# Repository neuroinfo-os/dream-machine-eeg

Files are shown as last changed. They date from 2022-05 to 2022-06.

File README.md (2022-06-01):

# Dream Machine
The Dream Machine, formerly known as *Traumschreiber*, is a lightweight, low-cost, mobile EEG device developed at the Neuroinforamtics group at Osnabrück University. This repository contains all affiliated projects and theses.

### This includes:
- BoardDesign: The Printed Circuit Board (PCB) design of the latest version and a collection of operation manuals of the most important hardware components
- Two App submodules, including the [standard version](https://github.com/denizmgun/EEG-DroidDesign) and an alternative version adapted for an [exemplary motor imagery task](https://github.com/denizmgun/DreamMachineThesisMod)
- The embedded system and Bluetooth Low Energy (BLE) implementation
- An implementation to perform an "Eyes Open, Eyes Closed" experiment with Labrecorder and lab streaming layer (LSL) as [submodule](https://github.com/mvidaldp/pylsl-keyboard-trigger)
- A collection of theses written with (older) versions of the Dream Machine   

*Please do not hesitate to contact us with any questions or ideas (Paria Samimi: psamimi@uni-osnabrueck.de, Laura Krieger: laura.krieger@uni-osnabrueck.de).*

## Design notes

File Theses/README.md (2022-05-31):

# Traumschreiber
The Traumschreiber system is the subject of several theses covering different research areas within Cognitive Science and Neuroinformatics. Here, the theses are collected. The following gives a brief summary of the individual projects.

#### _The Traumschreiber System - Enabling Crowd-based, Automated, Complex, Polysomnographic Sleep and Dream Experiments_ - K. Appel, Dissertation

In this dissertation the development of the Traumschreiber System as well as its evaluation is presented. The high-tech sleep mask was developed to enable naive crowd
subjects to perform complex polysomnographic sleep and dream experiments at home. It is shown that on the one hand the quality of polysomnographic data recording – including measurements of EEG, EOG, EMG and ECG–, can compete with commercial medical sleep laboratory systems. On the other hand, it was shown with two field studies that even novice subjects can conduct sleep experiment at their homes with the Traumschreiber.

## App Development

#### _Design and implementation of an Android app to  record, store and manage EEG signals_ - R. A. Rojas Campos, Master's Thesis (August 2019)

This thesis describes the most advanced Traumschreiber app to date. With the Android app, the user can collect, plot, save, manage, and share EEG sessions, recorded with the Traumschreiber system. It furthermore introduces a chatbot expert, used to inform the user about epilepsy and presents general information about epilepsy in a clear and accessible way. The code is available [in this repository](https://github.com/adrocampos/EEG-Droid).

#### _Developing and designing a mediator smartphone application for portable sleep EEG recording and biofeedback with focus on the end user experience_ - M. Jäkel, Bachelor's Thesis (February 2017)

This thesis reports on the implementation of a prototype Android application that introduces users to the sleep mask. With the app, users can, among other, connect the Traumschreiber via Bluetooth to their phones, enabling them to visualize recorded EEG data.

## Detection of Event Related Potentials with the Traumschreiber

#### _Studying Neural Correlates of Mind Wandering with Mobile EEG_ - M. Bammel, Bachelor's Thesis (April 2020)

This thesis constitutes a replication of a study by Braboszez and Delorme (2011) who identified neural markers of low alertness during mind wandering with the Traumschreiber. The experiments expose a significantly decreased alpha and beta frequency band power during mind wandering. However, the replication demonstrates that studying higher cognitive functions in a mobile setup using the Traumschreiber does not yield equivalent results compared to a stationary research graded EEG system. The full sourcecode of the project is available [in the author's repository](https://github.com/mbammel/BscThesis).

#### _Auditory Evoked Potentials with Mobile EEG_ - M. Vidal De Palol, Master's Thesis (March 2019)

This project combines the development of an Android App for real-time EEG visualization and recording and an experiment to assess the capability of the device for recording Auditory Evoked Potentials.

#### _Measuring vMMN, P300 and AEPs with a mobile EEG system_ - M. Reimann, Bachelor's Thesis (September 2018)

Within this thesis the potential of the Traumschreiber as mobile EEG system is explored by evaluating its usability and ability to detect event-related potentials (ERP). It is shown that the device is able to produce good and very good results for the ERP under consideration.

#### _Analyzing event-related potentials in 8-channel EEG data using machine learning methods_ - A.-K. Schalkamp, Bachelor's Thesis (September 2018)

This thesis describes a study performed to evaluate whether EEG data acquired with the Traumschreiber can be used with traditional and single-trial analysis. Furthermore, it expands on the importance of electrode placement.

## Eye Position and Gaze Estimation

#### _Eye gaze estimation and gesture recognition using mobile EEG, An application for sleep communication_ - V. Amo Olea, Master's Thesis (September 2019)

Within this project a real-time eye-gaze estimation and gesture recognition
system using Electrooculography (EOG) was developed. A Convolutional Neural Net was trained to recognize eye-typing gestures and three command gestures from movement with closed eyes.

#### _Extracting Eye Positions from Electrooculographic Recordings Using a Machine Learning Approach_ - F. Laubisch, Bachelor's Thesis (September 2016)

In this thesis the relationship between EOG data provided by the Traumschreiber and eye position obtained with a wearable eye tracking device is assessed. It is shown that the sole EOG data is not yet sufficient to produce reliable eye tracking information.

## Sleep and Lucid Dreaming Research

#### _Conducting a Polysomnographic, Automated Auditory Stimulation Sleep Experiment Using a Portable High-Tech Sleep Mask_ - L.S. Mandt, Bachelor's Thesis (April 2017)
The field study discussed in this thesis evaluates the portable high-tech sleep mask for home-based sleep experiments using polysomnography. Additionally, it examines whether the arousal threshold of individual participants can be determined by exposing them to auditory stimulation during the night.

#### _The Scienticity of Lucid Dream Research - A Theoretical and Empirical Approach_ - K. Lüth, Bachelor's Thesis (July 2015)

This work discusses the science-theoretical and historical background of lucid dream research. It presents a survey concerned with the attitude the public has towards the field. The survey showed that the public has a positive opinion.

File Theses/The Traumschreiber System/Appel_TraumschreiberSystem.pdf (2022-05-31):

# The Traumschreiber System

Enabling Crowd-based, Automated,

## Complex, Polysomnographic Sleep and Dream Experiments

Dissertation

Kristoffer Appel

## Abstract

Sleep and dreaming are important research topics. Unfortunately, the methods for researching them have several shortcomings. In-laboratory polysomnographic sleep and dream research is a costly, time-consuming and effortful endeavor, often resulting in small subject counts. Moreover, the unfamiliar sleeping environment can lead to distorted measurements as compared to the natural sleep environment at the subject’s home.

Conducting sleep and dream experiments in the field by a crowd of subjects could be a solution. However, complex experiment paradigms cannot be investigated this way, because there are no tools available, which enable naive subjects to carry out complex polysomnographic studies on their own.

The Traumschreiber system, which is developed and evaluated in this dissertation, offers a solution to this problem. It consists of a high-tech sleep mask and a minicomputer, and enables naive crowd subjects to perform complex polysomnographic sleep and dream experiments at home. On the one hand, it instructs the crowd subject, what to do when. On the other hand, it controls the experiment during the time the subject is asleep, analyzing the data in real-time using state-of-the art machine learning techniques. The rationale behind is to enable a big data approach to sleep and dream research, using the data recorded by a crowd of subjects for large-scale investigations about sleep and dreaming, with low costs for the researcher.

After describing the development process of the Traumschreiber system, its usefulness regarding crowd-based automated polysomnographic field studies is evaluated. First, it is validated against a commercial medical polysomnographic sleep laboratory system, demonstrating its good polysomnographic data recording capabilities – including measurements of EEG, EOG, EMG and ECG –, which enable the researcher to identify typical sleep patterns like slow waves or rapid eye movements as well as sleep stages in the recorded data.

Furthermore, two field studies show, that the Traumschreiber system can be used successfully by naive subjects to conduct complex sleep experiments at their homes. This includes acoustic stimulation of the sleeping subject as well as sleep stage dependent activities of the system. The sleep staging algorithm implements a Keras/Tensorflow based neural network approach, which demonstrates the system’s readiness for state-of-the-art machine learning techniques. However, the currently used neural network is kept very simple and can determine the sleep stage not very reliably; it should be further developed and trained on more data of more subjects.

The Traumschreiber system will be made available under an open source license, enabling any researcher to use, modify or further develop it. A description, how to produce arbitrarily many entities of the Traumschreiber system, is given in this dissertation and shows that one system can be produced at low costs in a short amount of time (production costs per piece around 140 EUR plus 80 EUR for the other parts of the system, production time: one hour per item).

Taken together, a new tool for sleep and dream research is now available, which enables a crowd-based approach of gathering polysomnographic data from complex sleep and dream experiments with only low resource needs for the scientist.

## Table of Contents

2.3.3.2 Description of the preparation steps for a Traumschreiber system study....57

3.1.2.2.3 Real-time data processing using encapsulated, modular scripts.......77

3.2.3 Third study: Preparing polysomnographic crowd experiments | 96
3.2.3.1 Description of production work step and cost analysis | 96
3.2.3.2 Programming the experiment | 107
3.2.4 Fourth study: A crowd-based polysomnographic experiment | 108
3.2.4.1 General results | 108
3.2.4.2 Data quality | 109
3.2.4.3 Sleep quality | 115
3.2.4.4 Ease of use, comfort and durability of the Traumschreiber system | 115
3.2.4.5 Feedback of the subjects to the sleep mask and the experiment | 116
3.2.4.6 Automatic sleep scoring algorithm and subject-specific adjustment | 116
3.2.4.7 N3 and REM sleep differences | 118
3.2.4.8 Sleep depth | 119
3.2.4.9 Workload of the experimenter and costs of the experiment | 120
4 Discussion | 121
4.1 General discussion | 121
4.2 Discussion of the development process and evaluation studies | 123
4.2.1 Discussion of the development process | 123
4.2.2 Evaluation studies | 124
4.2.2.1 First study: Sleep laboratory validation | 126
4.2.2.2 Second study: Home-based prototype study | 127
4.2.2.3 Third study: Preparing polysomnographic crowd experiments | 128
4.2.2.4 Fourth study: A crowd-based polysomnographic experiment | 129
4.3 Future research directions and prospects | 132
4.3.1 Future research directions | 132
4.3.1.1 Further developing the Traumschreiber system | 132
4.3.1.2 Suggestions for further studies with the Traumschreiber system | 135
4.3.2 Future prospects | 137
5 References | 139
Appendices | 150

## Figures

Figure 3.13: Night overview plot | 82
Figure 3.14: Detailed view plot | 82
Figure 3.15: The events dropdown menu | 83
Figure 3.16: Specifying a filter in the config xml file | 84
Figure 3.17: Manual sleep scoring with the Traumschreiber system | 85
Figure 3.18: Real-time sleep stage predictions of the Traumschreiber system | 86
Figure 3.19: The same predictions, averaged using a 20 minute sliding window | 87
Figure 3.20: Polysomnographic data recorded with the ALICE system | 88
Figure 3.21: The same data recorded with the Traumschreiber system | 89
Figure 3.22: Sleep staging comparison between the two systems | 91
Figure 3.23: Sleep quality in the first night and the control night | 92
Figure 3.24: Feeling of recovery after the experimental night and the control night | 93
Figure 3.25: Comparison of acoustic stimuli regarding arousals | 95
Figure 3.26: Back and front side of the equipped PCB | 97
Figure 3.27: All parts of 20 complete Traumschreiber systems | 100
Figure 3.28: The battery holder before cutting | 101
Figure 3.29: The battery holder after cutting | 101
Figure 3.30: Screenshot of the video tutorial (1) | 103
Figure 3.31: Sewing pattern for the sleep mask bag | 104
Figure 3.32: Screenshot of the video tutorial (2) | 105
Figure 3.33: Example of the bio signal calibration procedure | 109
Figure 3.34: Example of a nightly arousal procedure (1) | 110
Figure 3.35: Example of a nightly arousal procedure (2) | 110
Figure 3.36: Example of REM sleep recorded by the Traumschreiber system | 112
Figure 3.37: Unfiltered, raw data example of a recording with bad quality | 112
Figure 3.38: Example of a recording with good data quality | 113
Figure 3.39: Example of a recording with bad data quality | 113
Figure 3.40: Recording success during the second and third night | 114
Figure 3.41: Automatic sleep staging comparison | 117
Figure 3.42: Difference between REM and N3 sleep dreams (1) | 118
Figure 3.43: Difference between REM and N3 sleep dreams (2) | 118
Figure 3.44: Difference between REM and N3 sleep dreams (3) | 119
Figure 3.45: Difference between REM and N3 sleep dreams (4) | 119
Figure 3.46: Difference between REM and N3 sleep | 119

## Tables

Table 1.1: Comparison of consumer sleep recording devices | 31
Table 2.1: Overview of the main electric development iterations | 46
Table 3.1: Overview of the electrode positions and recorded channels | 70
Table 3.2: Detailed description of the experiment xml file commands | 74
Table 3.3: Polysomnographic graphoelements in both systems | 89
Table 3.4: Reasons were for having trouble falling asleep | 94
Table 3.5: Overview of the work steps for producing a Traumschreiber system | 96
Table 3.6: Recordings with a good EEG, EMG, EOG, and ECG signal | 114

## Abbreviations

AI | Artificial Intelligence
ADC | Analog-to-Digital Converter
BLE | Bluetooth Low Energy
CSV | Comma-Separated Values
ECG | Electrocardiography
ECTS | European Credit Transfer System
EEG | Electroencephalography
EMG | Electromyography
EOG | Electrooculography
EUR | Euro
FoR | Feeling of Recovery
FFT | Fast Fourier Transform
GUI | Graphical User Interface
HEOG | Horizontal Electrooculography
IC | Integrated Circuit
ICSD-3 | International Classification of Sleep Disorders – Third Edition
InAmp | Instrumentation Amplifier
JSON | JavaScript Object Notation
LED | Light-Emitting Diode
N1 | Sleep Stage N1
N2 | Sleep Stage N2
N3 | Sleep Stage N3
NDR | Norddeutscher Rundfunk
OpAmp | Operational Amplifier
PCB | Printed Circuit Board
Ph.D. | Doctor of Philosophy
POSIX | Portable Operating System Interface
RAM | Random-access Memory
REM | Rapid Eye Movement Sleep
SF-A | Schlaffragebogen A (Sleep Questionnaire A)
SQ | Sleep Quality
SWS | Slow Wave Sleep
UART | Universal Asynchronous Receiver Transmitter
UDP | User Datagram Protocol
USB | Universal Serial Bus
USD | US Dollar
VEOG | Vertical Electrooculography
XML | Extensible Markup Language

## Acknowledgements

I would like to thank quite a number of people, who supported me during my Ph.D. time. First of all, my supervisor, Prof. Dr. Pipa, from whom I learned a lot about doing science in general and about neuroinformatics, about advanced EEG analysis, about the “hidden” tasks a researcher has to do like networking and about budgeting. Moreover, I’d like to thank him for financing my Ph.D. position and parts of my experiments, even though sleep and dream science is not his main research interest, and for all the freedom throughout my Ph.D. and “letting me do my thing”.
Then, the other members of the PhD board, for their willingness to read and evaluate this dissertation: Prof. Dr. Kühnberger, Prof. Dr. Schredl and Prof. Dr. Dresler.
Next, I would like to thank all my co-workers in and around the office and the sleep laboratory, for valuable discussions and the good working atmosphere, and especially Mr. Leugering, who played a major role in developing the electro-technical parts of the hightech sleep mask discussed in this dissertation and parts of the software to steer it.
Then, all the students, who worked together with me in one of the several projects, on which this dissertation is built. First, the 10 bachelor students writing their thesis in the field of sleep and dreaming, with me as their supervisor. Second, all the students from the Student Initiative Sleep & Dream, who not only conducted a complete sleep laboratory study with 20 subjects in their leisure time, but also helped building up a very active sleep & dream student community in Osnabrueck, with excursions to far away countries, movie nights, lucid dreaming workshops and more. Third, the master students of the study project on Sleep and Memory, which I supervised, for all the efforts they put into conducting the first sleep laboratory study of this kind in Osnabrueck. Fourth, the students of my seminars “Sleep & Dream”, “Reading Club: Dreams and Dreaming”, and “Textile Design of a Hightech Sleep Mask I + II”, who also contributed to the success of this dissertation with inspiration and ideas, and Prof. Dr. Hähnel for the joint supervision of the textile design courses.
Next, I would like to thank the scientists from my personal research network, for sharing their knowledge with me, the inspiring discussions, and the great time at conferences, workshops and other meetings.

I would also like to thank Prof. Dr. Steiger and his group at the Max Planck Institute of Psychiatry in Munich for the opportunity to learn, how sleep research is conducted in a professional sleep laboratory, during my stay there as a visiting researcher.
Moreover, I would like to thank Prof. Dr. Young from the Muenster University Hospital, for his support, the opportunity to collaborate in a joint study, and especially the mediation of the donation of a professional sleep laboratory equipment to the Osnabrueck Student Initiative Sleep & Dream. Also I would like to thank Prof. Dr. König for letting me and the other students use his sleep research equipment.
Furthermore, I would like to thank the members of the Osnabrueck University ethics committee for their helpful advice and consulting during in total four ethics proposals. Next, I would like to thank Mrs. Jungeilges and Mrs. Eibisch for their help with all the administrative things, which need to be done in German bureaucracy.
Also, I would like to thank the Hans-Mühlenhoff-Stiftung zur Förderung leistungsfreudiger Jugend and the German Sleep Society for their financial support of my experiments, in total worth nearly 10.000 EUR, without which some studies of this dissertation could not have been conducted.
And, last, but not least, I would like to thank all my friends and family for the continuous support throughout the last years.
Thank you!

## Preface – Reflecting on my scientific activities

The highest academic degree, the Ph.D., is awarded for scientific achievements and proves that the holder of the degree is able to conduct elaborated scientific works on his or her own¹
. Before starting with the actual dissertation, I would like to briefly reflect on my scientific activities during the past four years.

It all started by following a personal interest of mine – lucid dreaming. I started researching it in my leisure time using a low-budget one-channel sleep EEG device. One year later, I created a student initiative about sleep and dreaming at my university in 2012. I motivated fellow students to conduct our own research in the field of sleep and dreaming using portable high-tech sleep devices, applied for funding from the general students’ committee, and organized regular meetings. Subsequently, I wrote my master’s thesis about how it is possible to communicate with (sleeping!) lucid dreamers in real-time. Fortunately, Prof. Dr. Pipa offered me the possibility to extend my research during a Ph.D.. I organized two university rooms and raised a large equipment donation of a medical device manufacturer, enabling me to conduct research in my own fully-equipped sleep laboratory. I went to the Max Planck Institute of Psychiatry in Munich as a visiting researcher, where I took part in a research project on lucid dreaming using a high-density 128 channel EEG, and learned, how to conduct professional sleep and dream research. This knowledge I then transferred to my sleep laboratory in Osnabrueck, and passed it on to fellow students of the student initiative, as well as during seminars I taught. Besides conducting research, life in academia also includes teaching. I offered courses worth 40 ECTS points in total; sometimes more than 100 students participated in my seminars. I supervised 19 bachelor’s and master’s theses and a one-year study project of ten master students.
The before mentioned student initiative grew steadily and became the largest young scientists sleep and dream research group in Germany, if not worldwide. We conducted workshops and experiments in the sleep laboratory and went on three scientific excursions, e. g. one week in spring 2016 to sleep researchers in Finland. More details

1 Osnabrueck University Ph.D. regulations “Promotionsordnung des Fachbereichs Humanwissenschaften der Universität Osnabrueck für die Verleihung des Grades Ph.D. in Cognitive Science” (2011), § 1.

about the student initiative can be found in the article “Kurzvorstellung der Studentischen Initiative Sleep & Dream Osnabrueck”, published in the journal “Somnologie” (Appel, 2017, see appendix).
There were several research projects of mine, which I conducted during the last years. I validated the sleep communication from my master’s thesis using polysomnographic recordings in my sleep laboratory at Osnabrueck university with experiment subjects from all over Germany. I recorded and analyzed lucid dreams with a high-density EEG at the Max Planck Institute Institute of Psychiatry in Munich. I conducted an online study about the success rate of a lucid dream induction technique, for which I used a self-developed website as a platform. I analyzed a dietary supplement regarding its effect on sleep and dreaming. I carried out a sleep laboratory study investigating the role, which sleep plays for memory processes. I conducted another questionnaire study about the public perception of lucid dreams. I successfully replicated the results of a recent study about a new lucid dreaming induction technique in my sleep laboratory, and started a study investigating the effects of lucid dreaming smartphone apps. I wrote a review paper about lucid dreaming, and an article about the same topic for the “DGSM Kompendium Schlafmedizin” of the German Sleep Society, which is used for educating purposes of sleep laboratory staff and medical doctors. I summarized a German dissertation about event-related potentials during lucid dreams and published it in a scientific journal in order to make it available to the English speaking scientific community. In many of these projects, I instructed and supervised undergraduate students, who carried out the experiments together with me as a part of their theses. Other smaller projects are not mentioned here.
I made most of this research available to the scientific community, e. g. at scientific conferences. Some of the research is already published in scientific journals as well, with the other not yet published works to follow after finishing my Ph.D.. A list of publications and conference presentations is attached at the end of this preface. Besides publishing my research in the scientific literature, it was important to me to transfer the new knowledge to the non-scientific public as well. I presented my research twice on television (NDR), in an international pop-sci magazine (The New Scientist), was interviewed by a large German internet magazine (Netzpiloten), and by journalists from Finland to Brazil (see appendix for examples).

Finally, I carried out other scientific tasks throughout my Ph.D.. From obtaining funds for my experiments (in total nearly 10.000 EUR), to writing and defending four complete ethics proposals, to acting as a reviewer in peer-reviewed journals four times. I connected the new Osnabrueck sleep and dream research to well-known researchers from various institutes, such as the Donders Institute (Nijmegen, The Netherlands), the Central Institute of Mental Health (Mannheim), the Max Planck Institute of Psychiatry (Munich), the Charité Sleep Competence Center (Berlin), the Muenster University Hospital, and Bern University (Switzerland), and cooperated with them in common research projects.
One project was not yet named in this reflection of my scientific activities: the Traumschreiber project. It is the main project of my Ph.D., and is described in larger detail in this dissertation.

List of scientific publications and conference presentations Appel, K., Pipa, G., & Dresler, M. (2017). Investigating consciousness in the sleep laboratory - an interdisciplinary perspective on lucid dreaming. Interdisciplinary Science Reviews, 1-16.

Appel, K., Pipa, G. (2017). Auditory evoked potentials in lucid dreams: a dissertation summary. International Journal of Dream Research, 10(1), 98-100.

Appel, K. (2017). Kurzvorstellung der Studentischen Initiative Sleep & Dream Osnabrueck. Somnologie, 21(3), 252-254.

Kern, S., Appel, K., Schredl, M., & Pipa, G. (2017). No effect of alpha-GPC on lucid dream induction or dream content. Somnologie, 21(3), 180-186.

Appel, K., Leugering, J., Pipa, G. (2016). Kommunikation mit Klarträumern in Echtzeit – aktuelle Möglichkeiten. Oral presentation at the 24rd Annual Conference of the German Sleep Society, Dresden, Germany.

Leugering, J., Appel, K. (2016). Traumschreiber: Eine Open Source Schlafmaske, die
Hirnaktivitäten | messen | und | beeinflussen | kann. | Oral | presentation | at | the
MetaRheinMainChaosDays of the Chaos Computer Club, Darmstadt, Germany.

Appel, K., Leugering, J., Pipa, G. (2016). “Traumschreiber”: Measuring and manipulating human sleep with a portable high-quality but low-cost polysomnographic system. Poster presentation at the 23rd Congress of the European Sleep Research Society, Bologna, Italy.

Appel, K. (2016). The Student Initiative Sleep & Dream Osnabrueck. Oral presentation at the 33rd Annual International Dream Conference, Kerkrade, Netherlands.

Appel, K., Kern, S. (2015). Phänomenologie luzider Träume und Induktionstechniken. Schulz, Geisler, Rodenbeck (Hrsg.) DGSM Kompendium Schlafmedizin. Ecomed Verlag, Landsberg, XVIII-3.9.1

Appel, K. (2015). The Student Initiative Sleep & Dream Osnabrueck. Oral presentation at the 23rd Annual Conference of the German Sleep Society, Mainz, Germany.

Appel, K., Pipa, G. (2015). Sleep Communication. Poster presentation at the Worldsleep Conference, Istanbul, Turkey.

Kern, S., Appel, K., Schredl, M., Pipa, G. (2015). Lucid dream induction using L-alpha glycerylphosphorylcholine. Poster presentation at the Worldsleep Conference, Istanbul, Turkey.

Appel, K., Pipa, G. (2014). Bidirectional, voluntary and conscious communication with arbitrary message content between a sleeping person and the waking world is possible. Poster presentation at the 22rd Annual Conference of the German Sleep Society, Cologne, Germany.

Appel, K., Erlacher, D., Pipa, G. (2014). Sleep Communication. Poster presentation at the Interdisciplinary College, Guenne, Germany.

## 1 Introduction

### 1.1 The basic ideas

All humans sleep on a more or less regular basis; sleep is one of the basic human needs. Moreover, everybody dreams, and even though some people have more trouble remembering their nightly hallucinatory experiences than others, dreaming is a core element of everybody’s sleep (Nir & Tononi, 2010).
If sleep or dreaming are disordered, this leads to undesired effects to the individual well-being on the one hand. On the other hand, the society as a whole is affected negatively by sleep disorders: The economic damage to the German national economy due to sleep disorders, for example, accumulated to 1.027 billion EUR in the year 2015 (Federal Statistical Office Germany (Destatis), 2017).
Since everybody sleeps and dreams, everybody is a potential subject for scientific sleep and dream studies. Thus, a crowd-based approach to researching this topic seems to be an idea worth investigating – not only since the more “classical” sleep and dream research methods (e. g. in-lab recordings) suffer from several limitations, as will be shown later in this introduction. The term “crowd-based” as used in this dissertation describes the idea to use the efforts and data of masses of subjects. The aim is to “crowd-source” (as in “outsource”) many of the tasks conducted by professional sleep researchers to the naive subjects, so that by far more data can be collected using this parallelized approach than would be possible the standard way. Crowd-based sleep and dream research would not necessarily mean, that the crowd would have to consist of many semi-professional sleep experts. It would be enough to enable a large group of naive subjects to conduct complex, state-of-the-art sleep and dream experiments with professional, polysomnographic methods on their own at home with easy-to-use tools.
Why was this not done until now? Actually, several approaches to measure sleep in larger subject populations outside the laboratory have been undertaken in the past, as will be described in greater detail later in this chapter – ranging from online questionnaire studies to dream diary studies to actigraphy studies. Without going too much into detail here already, it can be summarized that these approaches have several advantages and several disadvantages over measuring sleep in a sleep laboratory. Unfortunately, a crowd-based approach is obviously not well suited for sleep laboratory studies, as conducting in-laboratory research is an endeavor with high resource needs. At the same time, complex sleep experiments, which manipulate the sleep acoustically, which rely on sleep stage-dependent paradigms or which need other ways of interaction between the subject and the experimenter, cannot be conducted by naive subjects on their own at home – until now. Recent technological developments could be a game changer. Everybody knows, that electric components are getting smaller, cheaper and at the same time more powerful. The knowledge, how to construct complex technical devices, is made available in open source projects on the internet, e. g. for building an electroencephalograph (EEG) in the OpenEEG project²
. More and more powerful algorithms are developed in the field of artificial intelligence and one of its core disciplines, machine learning, as will be described later in this introduction.
Combining these developments, a system can now be built, which guides naive crowd subjects through a sleep or dream experiment and which conducts parts of it on its own. Such a small, transportable system would have to be capable of explaining to the inexperienced crowd subject, which experiment step to do when, for example how to record the brain activity using electroencephalography (EEG). Moreover, and equally important, it would have to be capable of conducting some parts of the experiment autonomously on its own, e. g. during the time the subject is asleep. Lastly, in an ideal case, setting up scientific experiments and programming this system would be very simple and not require a lot of time or programming knowledge of the sleep scientist. As a result, large-scale, crowd-based sleep and dream research becomes possible.
In the following theoretical part of this dissertation, the backgrounds of modern sleep and dream research will be characterized: its variety, its methodology and limitations. Afterwards, the technological progress in the field of artificial intelligence and machine learning will be briefly recapped, and it will be shown, how these technologies are used in the scientific study of sleep and dreaming already today. Ultimately, building on top of this theoretical work, a system will be developed and evaluated, which makes possible crowd-based polysomnographic sleep and dream experiments: the Traumschreiber system.

2 www.openeeg.sourceforge.net

### 1.2 The importance and variety of sleep and dream research

Scientific research about human sleep and dreaming is an important field with many facets, as can be seen from the following examples:
- In the field of memory consolidation, scientific sleep studies explore, how memory processes are influenced by sleep, e. g. how sleep helps to better memorize vocabulary, to consolidate freshly learned motor tasks, or to even rearrange existing memories and, thus, gain new insights into current problems. Moreover, it is researched, how these memory processes can be influenced and supported, for example using acoustic stimulation during sleep (for an overview, see Diekelmann (2014)).
- In the field of chronobiology, sleep researchers investigate, which biological processes cause sleep and wakefulness, how sleep is influenced by light exposure, by shift work, or by trans-meridian travel, how jet-lag can be reduced, and other related topics (Sack et al., 2007).
- Recurrent nightmares are just one out of around 60 sleep disorders, which the International Classification of Sleep Disorders lists (ICSD-3, American Academy of Sleep Medicine, 2014). About 5% of the population suffer from recurrent nightmares (Schredl, 2013), and a multiple of this suffer from sleep disorders in general, such as insomnia, sleep related breathing disorders, narcolepsy, or restless legs syndrom (Luyster, Strollo, Zee, & Walsh, 2012), underlining the importance of experimental human sleep research for clinical and therapeutic purposes.
- Lucid dreaming research is one of the most spectacular and fascinating subfields of sleep science – especially to laymen –, as can be seen by the occurrence of this topic in popular scientific journals and television shows (see examples for this in the appendix). Lucid dreams, in which the dreamer realizes that he or she is dreaming whilst staying asleep, offer fantastic opportunities not only for hedonistic purposes, but also as a tool used in several other academic disciplines, ranging from philosophy to sports science to psychotherapy (Appel, Pipa, & Dresler, 2017). Depending on the exact matter of investigation and the available resources, sleep can be assessed in multiple different ways.

### 1.3 Assessment of sleep and dreaming in the sleep laboratory

One way to assess sleep – and connected to it, dreaming – is to record it in a scientific sleep laboratory. The standard method is to conduct polysomnographic (from Greek “polus”: many, much, Latin “somnus”: sleep, Greek “graphein”: to write) measurements of a subject’s sleep, i. e. to record multiple physiological sleep parameters: brain activity measured by electroencephalography (EEG), muscle tension at the chin measured by electromyography (EMG), and eye movements measured by electrooculography (EOG). Recording these parameters allows for specialized data analysis, for example, a classification of discrete 30-second time intervals into the commonly used sleep stages, which helps to get an overview of the macrostructure of the sleep of a specific subject or larger populations: Besides the stage Wake, there is, on the one hand, rapid eye movement (REM) sleep, on the other hand, the non-REM sleep phases N1 (which mainly describes the transition period directly after falling asleep), N2 (“light” sleep), and N3 (“deep” sleep, also called slow-wave-sleep, SWS) (Rama & Zachariah, 2013). Standardized rules have been developed for classification purposes (Rechtschaffen & Kales, 1968; Iber, Ancoli-Israel, Chesson, & Quan, 2007), which are usually applied to the recorded data by manual (visual) scoring, or, lately, by using automatic sleep staging algorithms (Penzel et al., 2007). However, the historically evolved approach of using 30 second based sleep stage bins is criticized, as it has many drawbacks and as the digitalization of sleep recordings makes more advanced analyses possible, for example frequency-based analyses of the data using wavelets or Fourier transformations (Schulz, 2008).
When determining the above mentioned macrostructure of sleep, the occurrence of local patterns in the polysomnographic recordings is analyzed, so called graphoelements, which form the microstructure of the sleep. To these belong sleep spindles, K-complexes, slow waves, rapid eye movements, and several more (Rama & Zachariah, 2013). Furthermore, often additional polysomnographic characteristics are recorded, such as the heart rate or the heart rate variability using electrocardiography (ECG), movements of the legs, respiration, oxygen saturation levels, infrared camera videos, body movements, or snoring (Rama & Zachariah, 2013)).

Studies about the effect of auditory, visual or other stimulation of sleep on the sleep itself, on the occurrence of arousals or on cognitive performance during following waking phases belong to the first scientific experiments of modern sleep research (Davis, Davis, Loomis, Hervey, & Hobart, 1939; Dement & Wolpert, 1958) and are still a widely used tool in modern sleep and dream research (for a literature review, see (Braumann, 2016)³
).
The recorded data are then used to answer specific research questions in order to find out more about sleep or dreaming, both from theoretical as well as practical viewpoints, e.
g. “Do sleep spindles and occur more often after learning a declarative task?” (Gais, Mölle, Helms, & Born, 2002), or, “How does the intake of alcohol affect the sleep macrostructure and the sleep fragmentation?” (Williams, MacLean, & Cairns, 1983).

Polysomnographic sleep laboratory studies have a number of disadvantages. One of them is the limited availability of research-oriented polysomnographic sleep laboratories with adequate technical and personnel equipment (Ghegan, Angelos, Stonebraker, & Gillespie, 2006), not only in Germany and other Western countries, but to a much larger extent in less developed countries.
Furthermore, conducting polysomnographic sleep laboratory experiments is an effortful, resource-demanding and time-consuming activity (Van De Water, Holmes, & Hurley, 2011), as is illustrated in the following excerpt of the paper “Investigating consciousness in the sleep laboratory - an interdisciplinary perspective on lucid dreaming” (Appel, Pipa, & Dresler, 2017, full text in the appendix):
“3. A night in the sleep laboratory

[…] Subjects with frequent lucid dreams, which in addition have to be long enough to conduct scientific experiments within them, are hard to find. It is thus not uncommon to invite participants from the whole country or even from abroad for a lucid dreaming study, requiring effort for advertisement, recruitment, payment and traveling.

Preparation and performance of actual lucid dreaming experiments in the sleep laboratory are complex as well - besides the usual extensive procedures necessary to conduct sleep laboratory studies, including as a minimum

3 Bachelor’s thesis of Sophia Braumann, supervised by the author of this dissertation. See online appendix.

polysomnographic measurements of the brain activity by EEG, of eye movements by electrooculography (EOG), and of muscle activity by electromyography (EMG). For these measurements, electrodes are fixed on the scalp and in the face of the subject. […] As a result, preparation for the experiment can take several hours before the subject is sent to bed. In lucid dreaming studies with high-density EEG for topographical analyses or source localization of brain activity, for example, it takes two experimenters about three hours to instruct and prepare the subject, including fitting of the 128 EEG electrodes and measuring their positions and orientations.

Then the actual sleep recordings begin: In contrast to daytime EEG studies, where the subject usually sits still in front of a computer screen, sleeping subjects are turning around frequently, moving their heads, rubbing them into the pillow, pulling cables, and so on. Thus, lucid dreaming experimenters usually need to stay awake for the whole night in order to continuously supervise the quality of the recordings and to intervene in case of bad signal quality. There is nothing more frustrating for a lucid dream researcher than a bad EEG signal during the critical few minutes of a lucid dream. […]

The necessity to wake up subjects in case of a lucid dream without self-initiated awakening requires the experimenter to continuously monitor the eye recordings on the computer monitor throughout the whole night. While unfortunately still no automatized solutions for lucid dreaming LRLR eye signal detection in the sleep laboratory exist, some researchers have recently started developing such tools by applying methods from the field of machine learning and pattern recognition to automatically detect lucidity-indicating eye movements or bad EEG signals in real-time (e. g. Appel, 2013).

In the morning, when the subject declares that he or she cannot sleep any more, recordings are stopped, and it usually takes another one or two hours to let the subject fill out more questionnaires, to tidy up and clean the equipment, or to take a few other measures depending on the experiment. For example, a classical study protocol for motor skill training during lucid dreaming needs performance measurements of the chosen skill both in the evening and in the morning. All in all, the whole experimental procedure of recording one night including preparations and follow-up usually takes from 8 PM until 11 AM the next day – for a few recording minutes of data of interest in the best case scenario, i. e. the subject experiencing an actual lucid dream. In many cases, two or three consecutive nights are recorded in a row in order to reduce traveling demands on the subject, resulting in an extensive workload for the lucid dream researcher. Given all these efforts and constraints, it is not surprising that lucid dreaming studies often suffer from a limited number of participants – if exceeding the character of case-studies of single subjects at all.”

Even though this kind of sleep laboratory study is probably one of the extreme ones – in most cases subjects can be invited from the local area and often most of the recorded nights result in useful data – this insight into a lucid dreaming sleep laboratory study illustrates the immense resource needs of sleep laboratory studies:
- Time-wise for the experimenter or a commissioned person (e. g. a night watch), as he or she has to a) spend the evening in the laboratory preparing the experiment, b) stay awake the whole night in order to supervise the signal quality and to conduct the experimental tasks at night, such as collecting dream reports, applying stimuli, or waking up the subject at specific time points, c) in the morning for uncabling the subject, for collecting more questionnaires, and for cleaning up.
- Time-wise for the subject, as it a) has to spend the evening, night, and (sometimes) morning in the sleep laboratory, instead of sleeping at home, b) needs to travel to the experiment location and back, which might be in a different city, c) might be sleep deprived and thus needs more sleep the following night, due to the unfamiliar clinical sleep laboratory surrounding.
- Money-wise, as the sleep laboratory needs to be heated, cleaned, needs electricity and water, for washing the blankets, replacing materials from time to time, and – especially – for all the sleep laboratory equipment, which can cost several thousand EUR. Moreover, the personnel has to be paid, i. e. the night watch, cleaning personnel, and eventually additional research assistants.
- Infrastructure-wise, as suited rooms have to be allocated for sleep research use.

Besides all these high resource investments, it might, even worse, be the case, that the sleep laboratory environment influences the sleep to such an extent, that it is not comparable to the “natural” sleep at the subject’s home anymore, which one originally planned to study. One reason for this is, that individual needs of the subject such as their preferred time to go to bed are often hard to meet in the standardized procedures of sleep laboratory recordings. Another reason is the so called “first night effect”, which states, that the first night of sleep in a sleep laboratory usually contains more awake periods, and less REM sleep, than in consecutive nights (Agnew, Webb, & Williams, 1966). Hobson, Pace-Schott, & Stickgold (2000) explain nicely, why sleeping in the laboratory is less comfortable, more difficult and less deep for the subject:
“To appreciate this point, the reader need only imagine going to an unfamiliar place in an inner city neighborhood of dubious safety, encountering a technician
who is a stranger and often of the opposite sex, having ten electrodes affixed to the scalp with cement that smells like airplane dope and then being bid ‘goodnight’ and ‘pleasant dreams.’”

Furthermore, as Waterman, Elton, & Kenemans (1993) argue, can differences between home and in the laboratory recorded dreams occur. This is due to environmental factors such as the artificial setting or due to the interpersonal, communicative relationship between the experimenter and the subject in the laboratory, which might influence qualitative and quantitative aspects of dream recall and report.
Hobson et al. (2000) suggest, that there are three ways to deal with these limitations of sleep laboratory studies: a) by extending the number of nights for each subject to around seven, which has the disadvantage of increasing the efforts severely, b) by recording only one to four nights, and thus accept possible influences on sleep architecture and dreams, or c) to conduct the experiments as field studies at the subjects’ homes, using portable technology.

### 1.4 Conducting sleep experiments as field studies at the subjects’ homes

1.4.1 (Online) questionnaire studies

The simplest form of gaining data about sleep is the use of questionnaires or sleep diaries. These can either be used on their own, e. g. for collecting data in epidemiological studies, or in combination with further instructions for the subject, for example when assessing the effect of behavioral tasks on sleep.

As Goril & Shapiro (2013) point out, the main reasons for using standardized questionnaires and rating scales are a) that they are quick and accurate for finding a population of interest, e. g. with a specific sleep disorder such as recurrent nightmares, b) that they enable the researcher to monitor change and progress over longer periods of time, c) that they are quick and easy to evaluate and, in the case of standardized questionnaires, deliver validated results regarding the target they have been developed for, and d) that they allow for direct comparison of subject groups between different study locations and laboratories, for example in multi-site experiments. Moreover, they are relatively inexpensive in comparison to sleep laboratory studies, at least if no license fees have to be paid, and need far less resources.
There exist more than one hundred standardized sleep scales for assessing various kinds of sleep habits and disorders (Shahid, Wilkinson, Marcu, & Shapiro, 2012). Three exemplary and widely used scales in sleep research are
- the Pittsburgh Sleep Quality Index (PSQI), which measures the sleep quality and disturbances over a period of one month (Buysse, Reynolds, Monk, Berman, & Kupfer, 1989),
- the Epworth Sleepiness Scale (ESS), which measures daytime sleepiness (Johns, 1991),
- the Morningness-Eveningness Questionnaire (MEQ), which assesses the chronotype of a subject (Horne & Ostberg, 1976).
A German language questionnaire, which is designed for a differential diagnosis of sleep disorders and is used by the Osnabrueck sleep research group for excluding sleep disordered subjects from study participation, is the Landecker Inventar zur Erfassung von Schlafstörungen (LISST). The LISST is based on the International Classification of Sleep Disorders (ICSD) and discriminates between sleep disorders such as sleep-related breathing disorders, insomnia, narcolepsy, restless legs syndrom, and circadian rhythm disorders (Schürmann et al., 2001).
Besides using standardized questionnaires, it is of course also possible to develop own questionnaires based on the research question one wants to investigate, however, with the disadvantage that it is not possible to compare the results to norms then.
Questionnaire based studies can be conducted in an online fashion over the internet, saving time and resources. One example of such an internet based study with self-developed questionnaires (conducted by the author of this dissertation) is depicted in figures 1.1 and 1.2.

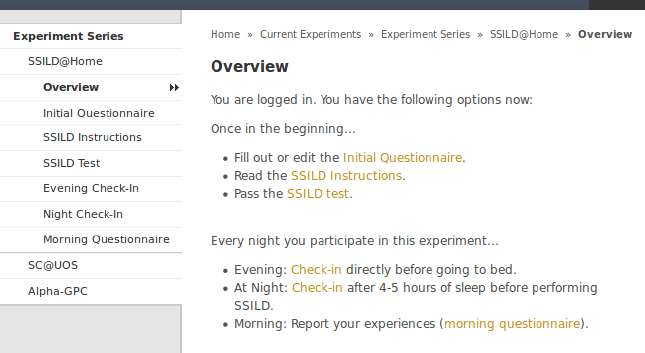
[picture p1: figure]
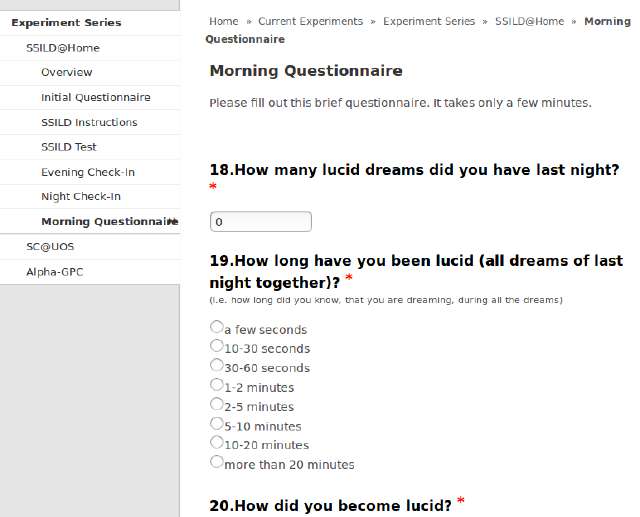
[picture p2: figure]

It is possible to extend the idea of questionnaire-based home studies, by supplying the subjects with further experimental materials, such as substances for intake (e. g. drugs or dietary supplements), measurement tools (e. g. saliva sampling) or stimulating tools (e. g.

Figure 1.1: Screenshot of an online study navigation, instructing the subject what to do when.

Figure 1.2: An exemplary sleep experiment online questionnaire.

glasses filtering out blue light to be worn in the evening). These tools can be of electronic nature or non-electronic. Electronic tools are discussed in the next section of this chapter. One exemplary questionnaire based field study analyzed the effect of a special type of self-administered dietary supplements on sleep and dreaming (Kern, Appel, Schredl, & Pipa, 2017, see appendix)⁴
. In this experiment, the subjects had to wake themselves up using an alarm clock after a given time period, open a letter containing either placebo or verum pills, continue sleeping, and, in the morning, report their dreams. The whole procedure was then repeated two more times. Even though this study is rather complex, it has to be noted, that drawing conclusions about sleep stages or other sleep characteristics – except the subjectively experienced ones assessed by the questionnaires – was not possible with such a design.

### 1.4.2 Field studies using electronic tools

Electronic devices exist, which measure sleep outside the laboratory environment at the subject’s home. There is a large variation, ranging from consumer products (smartphone apps, watches, but also devices capable of recording sleep EEG), to medical devices such as actigraphs and even portable polysomnographic tools similar to those in the sleep laboratory.

1.4.2.1 Portable medical sleep recording devices

Actigraphy and portable polysomnographic devices are the two main technologies in the field of medical sleep recording devices for home use, even though other approaches like bed sensors are developed as well (Van De Water et al., 2011).
Actigraphy is one of the most widely used medical devices in home-based sleep research (Slater et al., 2015). In most cases, actigraphy consists of a watch, which the subject wears around the wrist day and night, even though other places on the subject's body have been tried out with less recording success, too (Zinkhan et al., 2014). The watch contains an accelerometer, which measures arm movements in all directions. Most modern actigraphy devices measure additional parameters as well, for example brightness or pulse. It is possible, to infer from the recorded data, whether the subject is asleep or awake – at least to some degree (Marino et al., 2013). Actigraphy is often used to study

4 Originally conducted as the bachelor’s thesis of Simon Kern, supervised by the author of this dissertation.

circadian rhythms or sleep illnesses like the shift work disorder. However, it is not recommended as a diagnostic tool for routine diagnoses (Kushida et al., 2005; Morgenthaler et al., 2007). The advantages of actigraphy as compared to in-laboratory polysomnography are, that it is less expensive, less complicated to use, ubiquitously available, and most likely without a first night effect (Ancoli-Israel et al., 2003). The disadvantages of actigraphy are, that it cannot measure the brain activity (EEG), eye movements (EOG) or muscle tension (EMG), that it tends to overestimate the amount of sleep and underestimates the amount of wakefulness, and that not all devices have been validated against polysomnography (Ancoli-Israel et al., 2003; Lichstein et al., 2006; Sadeh & Acebo, 2002).
Portable polysomnographic devices, which measure EEG, EOG, EMG and often also ECG, are available, too, and can be used successfully for unattended sleep recordings at the subject’s home (Bruyneel & Ninane, 2014). Subjects usually cannot put on the devices on their own (Myllymaa et al., 2016), a trained sleep technician is necessary for connecting the subject to the device in the evening, which is a major disadvantage in comparison to actigraphy or to the consumer devices described below. Moreover, this technology is more expensive, complex and time-consuming than other portable sleep recording technologies. The main advantage over other portable sleep recording devices is that it allows complete sleep evaluation including EEG, EOG, EMG and often more. Compared to in-laboratory polysomnography, the subjects’ sleep tends to be better at home, and the costs are lower, however, the data quality is slightly worse (Campbell & Neill, 2011).
Only few data are available regarding the material costs and the cost of actually using home-based polysomnographic devices compared to in-laboratory recordings (Bruyneel & Ninane, 2014). Based on the expenses at the University Osnabrueck sleep laboratory and based on personal communication with several exhibitors at the sleep technology exhibition of the 24th Annual Meeting of the German Sleep Society, 2016, it can be estimated, that state-of-the-art actigraphy watches can easily cost more than 600 EUR, a complete polysomnographic equipment costs several thousand to tens of thousand EUR, with portable polysomnographic sleep recording devices lying in between. The costs for personnel and other expenses are not included in this, but can reach several hundred EUR per night as well. However, this strongly depends on the country, in which the recording takes place (Bruyneel & Ninane, 2014).

The before described medical sleep recording devices are sold commercially, are proprietary (closed) technology and do not allow real-time access of the raw data, displaying further disadvantages of this type of technology.

1.4.2.2 Sleep recording consumer products

A large number of consumer products, which claim to measure human sleep characteristics, are available on the market or preparing a market entry. Even though it was not able to actually measure sleep, the NovaDreamer sleep mask (based on the DreamLight sleep mask described in (LaBerge, Levitan, Rich, & Dement, 1988)) was probably the first commercially available technical sleep consumer product. Its purpose was to influence the subject’s sleep and to induce lucid dreams using visual stimulation (blinking lights).
It took until 2009, when the first consumer product was developed, which could actually measure sleep. Furthermore, it was capable of sleep staging the data in real-time and was even sleep laboratory validated: the Zeo system (Griessenberger, Heib, Kunz, Hoedlmoser, & Schabus, 2013; Shambroom, Fábregas, & Johnstone, 2012). The Zeo system consisted of a wireless headband with textile electrodes, which recorded a one-channel prefrontal EEG, and a small station, which received the data in nearly real-time and calculated and displayed the sleep stages. Moreover, it was possible to access the raw data by connecting a cable to the station, and it was very inexpensive (around 150 EUR). However, due to a not working business model, the Zeo went out of business in 2013 (Orlin, 2013).
Nowadays, several products have filled the gap, which was left after the Zeo shutdown. Leaving smartphone apps and fitness trackers aside, which are very popular, but at the same time have very poor quality for measuring sleep and wakefulness (Kolla, Mansukhani, & Mansukhani, 2016), these can be divided into two branches. On the one hand, there are devices, which mainly aim at actual sleep recording. On the other hand, consumer products exist, which mainly aim at measuring brain activity in general, but could be used for measuring sleep as well. Both types of devices cost around 300-800 USD⁵
and most of them are produced by small startups, which are financed via crowdfunding campaigns.

5 Please see the companies’ websites for the latest price.

The consumer products, which are targeted at measuring brain activity during wakefulness or mediation, are not suited well for recording sleep data: Either because they are uncomfortable to wear a whole night long due to a rigid corpus (OpenBCI ⁶
, Emotiv
EPOC+⁷
), because they are not designed for unattended use during sleep experiments in the field (OpenEEG⁸

) or because the batteries last only around three hours (Muse⁹ ). A
sleep recording subproject exists for the OpenBCI, which aims at enabling professional sleep research experiments with the device. However, the costs for setting up this sleep measuring version are comparatively high (almost 950 USD)¹⁰ and actually measuring sleep data is complicated, if not impossible for not inexperienced subjects.
Ten consumer devices could be identified after an extensive internet research, which claim to be able to record sleep data (see table 1.1). Most of them focus on lucid dream induction, relaxation in general, or improving the sleep quality. However, as of November 2017, most of them are not (yet) available. It has to be noted, that the development of most of the devices, which are not available until the date of writing this, was delayed by months or even years. It can thus only be speculated, when these devices can be bought. Furthermore, it has to be noted, that crowdfunding campaigns were canceled in at least two cases before the development of the devices was finished, even though several hundred thousand EUR were collected.
Major disadvantages of the consumer sleep recording devices are, that the data quality is questionable, especially since most of them record only one or two electrophysiological channels. Moreover, nearly all of the devices for conducting sleep experiment measurements at the subject’s home are sold by commercial companies for profit ¹¹. As a result, the systems are proprietary technology, i. e. not open, which means that the exact way, how they function, is kept secret. Consequently, the researcher has to believe the manufacturer about what is being measured and cannot know in detail, how the signal is processed (e. g. filtered) inside the system. Additionally, a way to access to the raw data in

6 www.openbci.com
7 www.emotiv.com
8 www.openeeg.sourceforge.net
9 www.choosemuse.com
10 www.spisop.org/openbci
11 This is especially the case for the medical portable devices, and also applies to sleep laboratory systems.

real-time is available only in a few cases, and also the software for analyzing the data is often proprietary. This makes it often impossible for researchers to adapt the software to specific experimental needs, which exceed the standard data processing pipeline.

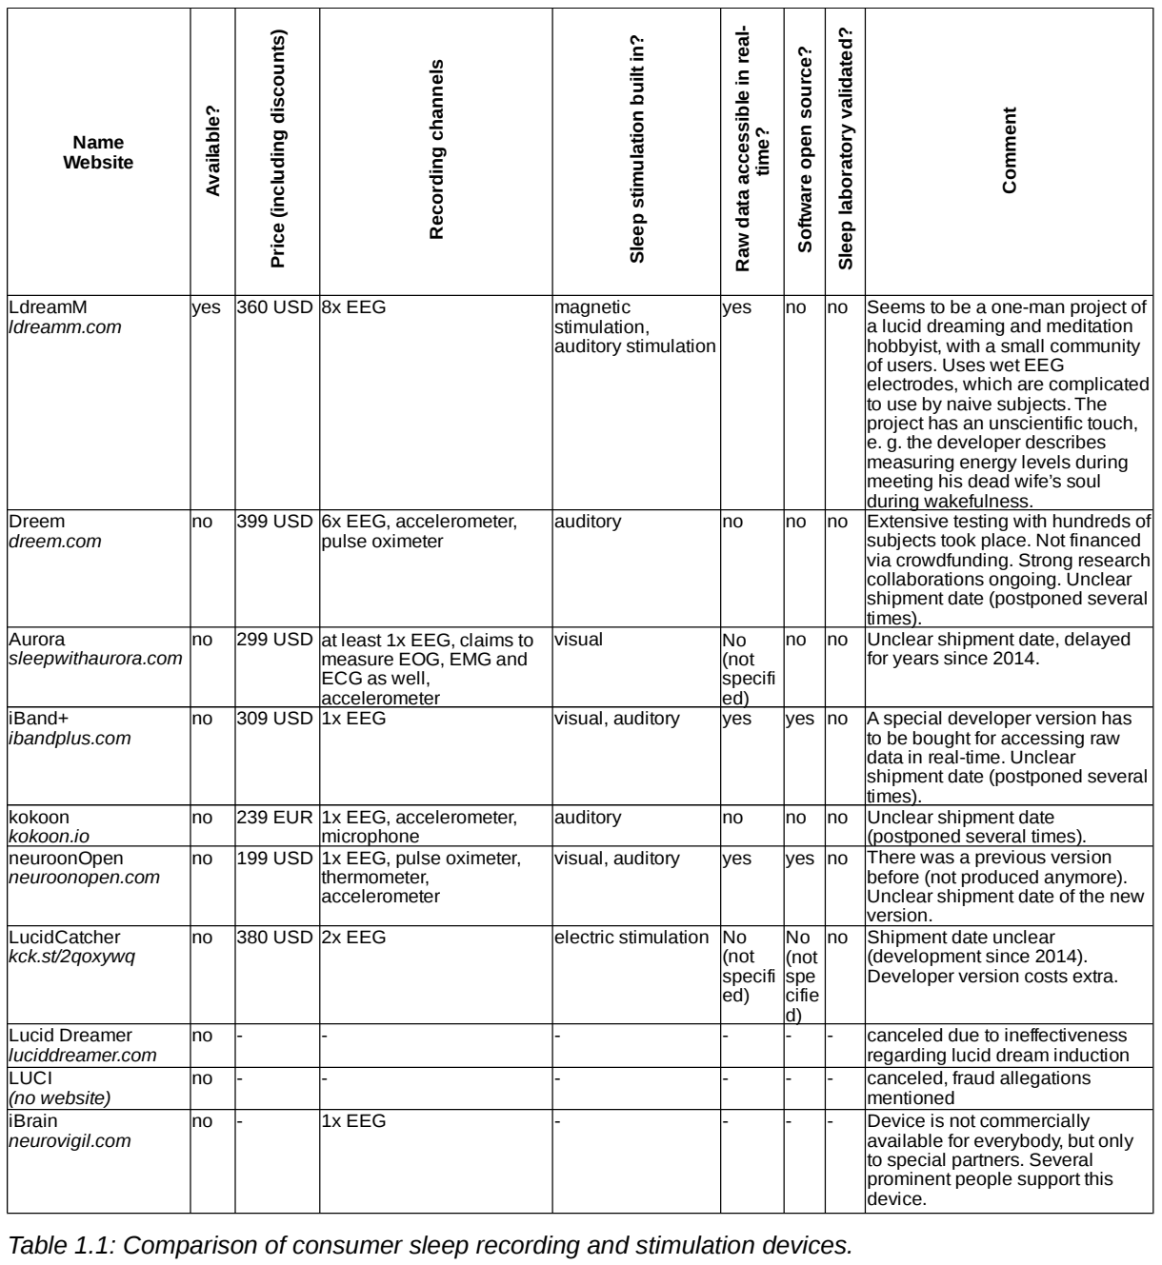
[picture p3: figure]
Available?; Price (including discounts); Recording channels; Sleep stimulation built in?; Software open source?; Sleep laboratory validated?; Com; ment; yes 360 USD 8x EEG; yes; no 399 USD; auditory; no 299 USD; visual; no 309 USD 1x EEG; visual, auditory; yes no; no 239 EUR; no 199 USD; no 380 USD 2x EEG; electric stimulation; 1x EEG; Name Website; Raw data accessible in real-; time?; LdreamM ldreamm.com; magnetic stimulation, auditory stimulation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

Table 1.1: Comparison of consumer sleep recording and stimulation devices.

Even though no exceptions to this are available regarding devices designed for actual sleep recording, the OpenBCI project and the OpenEEG project show an alternative way, by open sourcing their hardware specifications and software code. Open hardware and open software in this context mean, that all the knowledge needed for reproducing the system is made publicly available, even though specific licenses can apply e. g. for commercial usage. Similar open developments take place in other contexts as well (see figure 1.3), for example in the scientific literature (open access journal articles) or in projects like Wikipedia (open knowledge).

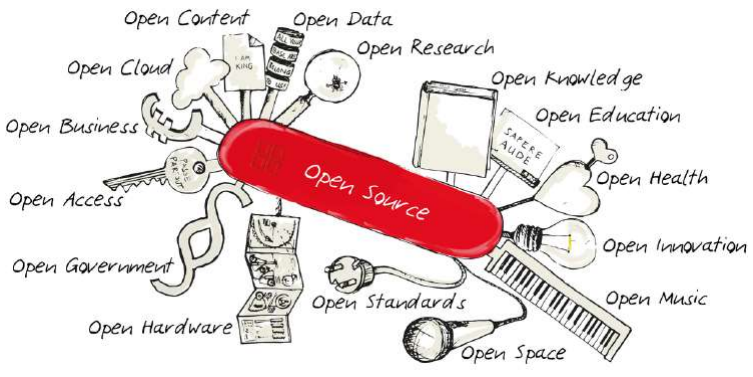
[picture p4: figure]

### 1.5 Artificial intelligence

If a researcher wants to let naive crowd subjects conduct complex, interactive polysomnographic sleep or dream experiment at their home, he or she cannot just hand out sleep recording devices to the subjects. Instead, each subject needs to be instructed how to use the device, and someone has to control the experiments during the time the subject is asleep. For example, in a sleep stage dependent experimental paradigm, in which the subject is woken up during a specific sleep stage in order to fill out a questionnaire, someone needs to classify the sleep data in real-time.
Artificial intelligence (AI) is a buzzword, which is used in all kinds of contexts. As the Stanford One Hundred Year Study on Artificial Intelligence states, there are many definitions of what AI is, with none being universally accepted (Stanford University, 2016).

Figure 1.3: Overview of open source fields. Author: Johannes Spielhagen, Bamberg,

Germany - CC BY-SA 3.0, https://commons.wikimedia.org/w/index.php?curid=27179850

The authors write that “a useful one” by (Nils J. Nilsson, 2009) is the following: “Artificial intelligence is that activity devoted to making machines intelligent, and intelligence is that quality that enables an entity to function appropriately and with foresight in its environment.”
Transfered to machines, which are used in complex polysomnographic sleep and dream experiments, AI could be used to take over those tasks, which are normally conducted by a human intelligence (in this case, the sleep researcher or night watch). For example, an AI, which features machine learning algorithms, could be trained to detect sleep stages and to carry out specified experiment tasks based on this, replacing the human intelligence by an artificial counterpart. Before describing, in how far AI is used in the sleep and dream research context nowadays already, some background information on AI and one of its most important subfields, machine learning, is given.

### 1.5.1 Brief historical overview

The foundations of AI have been laid a long time ago (for a more detailed overview, see for example Russell, S. & Norvig (1995)). Philosophers like Aristotle, who lived in the ancient Greece, already discussed the idea, that the mind is in some ways like a machine, which operates on knowledge encoded in an internal language. By using thought, it can be decided, which actions should be taken. Later, mathematicians like George Boole, Thomas Bayes or Gottfried Leibniz started to develop tools to manipulate statements of logical certainty as well as uncertain, probabilistic statements, and the idea to use algorithms for reasoning purposes was born. Again several centuries later, scientists from other academic fields such as psychology and linguistics contributed to the foundations of AI by adding insight about the mechanisms of human intelligence, already demonstrating this area of research’s multidisciplinarity.
The term artificial intelligence itself was first coined in the proposal for the famous Dartmouth workshop written in the year 1955 (McCarthy, Minsky, Rochester, & Shannon, 1955), which was held one year later in summer 1956. This workshop is generally seen as the official birth date of modern AI research. A huge AI hype followed, after the first “intelligent” systems were developed (e. g. ELIZA, an interactive program, which was able to carry on a dialogue in English language on any topic (Joseph Weizenbaum, 1966)), and huge promises were made by prominent AI researchers ("machines will be capable, within twenty years, of doing any work a man can do." - Herbert Simon, 1965 (Goble, 2012), “In from three to eight years we will have a machine with the general intelligence of an average human being.” - Marvin Minsky, 1970 (Darrach, 1970)). At that time, the first expert system was developed as well, automating the decision-making process and problem solving behavior of organic chemists by using detailed, task-specific knowledge as a source of heuristics and seeking generality through automating the acquisition of such knowledge (Lindsay, Buchanan, Feigenbaum, & Lederberg, 1993).
However, after James Lighthill (1973) reports to the British Science Research Council that “in no part of the [AI research] field have discoveries made so far produced the major impact that was then promised”, governmental support for AI research was reduced dramatically. What followed, is generally called the “AI winter”, describing this period of time with disappointed and lost public interest in the field and very limited funding. However, over the years, new approaches occurred. Probabilistic methods were found to function better than rule-based systems, for example in the area of language translation (Brown et al., 1988). In 1997, the IBM computer Deep Blue beats a reigning world chess champion for the first time. Similarly, the quiz show “Jeopardy!“ was won by an AI in 2011 using a huge knowledge base, and an AI based on artificial neural networks and tree search defeated the best human Go player in 2016. Modern AI research has many facets, ranging from understanding human speech, to competing at a high level in strategic games, to controlling autonomous cars.

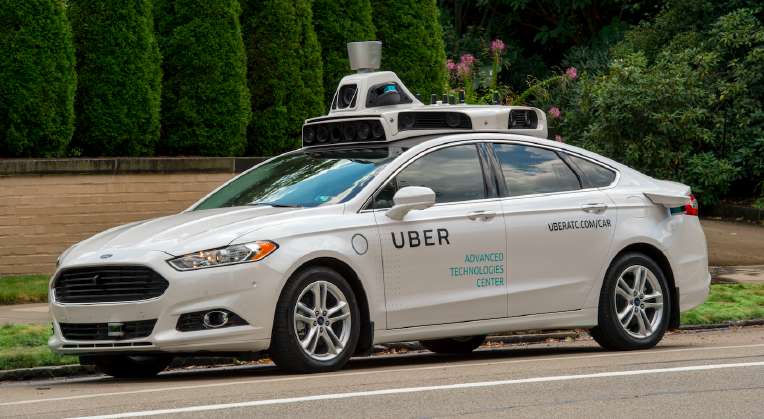
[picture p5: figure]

Figure 1.4: Example of an autonomous car controlled by an artificial

intelligence. Image source: https://www.digitaltrends.com/cars/chicago-may-ban-autonomous-cars/

As can be seen by this brief historical overview, and as is concluded by (Russell, S. & Norvig, 1995), too, the field of artificial intelligence research underwent several cycles of success and cutbacks, and new methodological approaches were developed constantly, how to create intelligent machines. Interestingly, the border of what can be seen as being “intelligent“ was moved further and further, never being reached. Only a short time after a task was accomplished by an artificial intelligence, which was previously being stated to require intelligence to solve, this point of view was changed, creating the so called AI effect (McCorduck, 2004). Until today, all forms of AI have rather been experts in a specific field or kind of task (e. g. playing chess) – the so called weak form of AI. The opposite, a strong AI displaying all forms of human intelligence (similar: artificial general intelligence) has not been created, and a valid question is, how such a form of intelligence could be tested (Goertzel, 2014). A number of tests have been proposed for this, with the so called Turing test being one of the most prominent ones. In brief, it tests, whether an AI is able to show intelligent behavior, which is indistinguishable from human behavior, by letting human interrogators ask written questions simultaneously to a human and an AI, trying to figure out from the answers, who is who (Turing, 1950).

### 1.5.2 Machine learning and deep neural networks

Recent AI research has seen a lot of progress in the field of machine learning. This subfield of AI describes the computer’s ability to learn without being explicitly programmed (Samuel, 1959). Even though other promising machine learning approaches exist, for example the decision tree-based random forests (Breiman, 2001), one extremely powerful technology are the so called deep neural networks (Lin, Tegmark, & Rolnick, 2017). Artificial neural networks (for a detailed, formal introduction and a broader overview of the topic, see Schmidhuber (2015), Yegnanarayana (2009) or Goodfellow et al. (2016)) are based on the idea of modeling natural neural networks in computers – an approach, which foundations were laid by McCulloch & Pitts (1943). Like their natural counterparts, these digital neuron networks can receive inputs, transform the input and generate outputs. The transformation of the input takes place both in the neurons themselves (e. g. by summing up all inputs and applying a mathematical activation function to it in order to obtain an output value) and due to the complex, non-linear interplay between the neurons, with the output of one neuron being used as input to other neurons.

The strength of this approach arises, when the artificial neural network is modified according to certain rules – a process called learning. The goal of this is to let the neural network learn to generalize over different inputs, in other words, to be able to create meaningful output values also for before unseen data. Supervised and unsupervised learning are two categories of this, with supervised learning describing the idea of presenting input-output pairs to the network, making the network learn to calculate a specific output for given inputs, e. g. for pattern recognition purposes. In the case of unsupervised learning, the network is only presented inputs, and tries to describe a hidden structure in the input, e. g. finding clusters in the data.
The first idea, how a learning rule for modifying a network during the learning process could look like, was introduced by (Hebb, 1949), suggesting that “cells that fire together, wire together”, i. e. if neuron A in a network often causes neuron B having a high output value, the connection between them is strengthened. Important other learning algorithms like the backpropagation algorithm followed (Rumelhart, Hinton, & Williams, 1986), enabling the neural networks to learn more complex functions than was possible with the Hebbian learning rule.
Organizing the learning process is commonly subdivided into two parts: training and testing. During training, the network is presented a subset of the available data (training data set), and for each data point, an error function compares the network’s output with the target output values. Based on these deviations, the modifications of the network are applied. Simultaneously, a second subset of the available data (validation data set) is used in order to validate the neural network’s performance on unseen data, which helps prevent the so called overfitting, i. e. preventing the neural network from learning only the exact training examples, but not generalizing over them. Finally during testing, after the training and validation process resulted in a sufficiently good performance of the neural network on the validation data set, it is tested on the third part of the available data (the test data set), in order to estimate the neural network’s ability to handle completely new, unseen data. Various types of neuron models, activation functions, learning rules, error functions and network architectures have been developed, resulting in more and more powerful artificial neural networks, which are capable of solving a manifold of problems¹². Moreover, several

12 For the sake of brevity and since these details are not of the greatest importance for the rest of this dissertation, the interested reader is referred to the literature cited at the beginning of the chapter for further information.

open source frameworks such as Keras (Chollet, 2015) or tensorflow (Abadi, Barham, et al., 2016) exist for developing. Additionally, due to the increasing computational power of nowadays computers, and due to further theoretical improvements in the field, extremely large artificial neural networks can now be constructed and trained successfully (LeCun et al., 2015). This lead to the phrase “deep learning”, as the neural networks can consist of dozens or even hundreds of layers. Moreover, massive amounts of training data for many different problems is available nowadays due to the internet, smart sensors and devices, increasing the performance of neural networks further, succeeding human performance in many fields. One example for this is the success of deep neural networks at image classification, exceeding human performance in describing what can be seen in a picture (He, Zhang, Ren, & Sun, 2016).

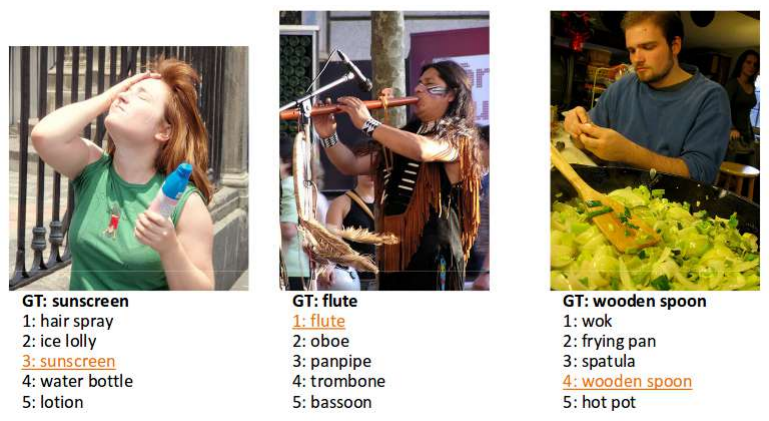
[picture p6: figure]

Figure 1.5: This figure from (He et al., 2016) depicts image labels generated by an artificial neural network (numbered 1 to 5) as well as the "ground truth" (GT), i. e. the official label of the image from the image recognition competition.

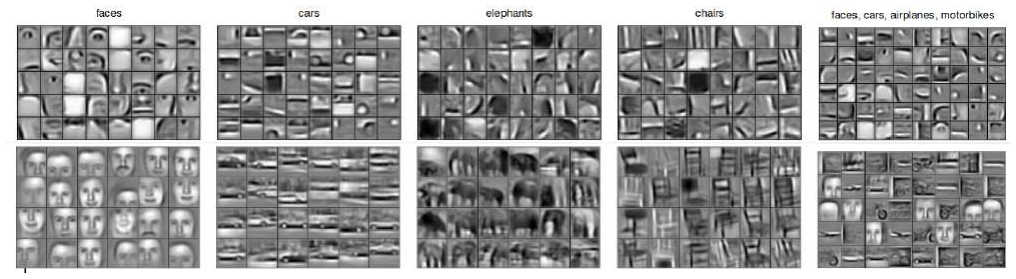
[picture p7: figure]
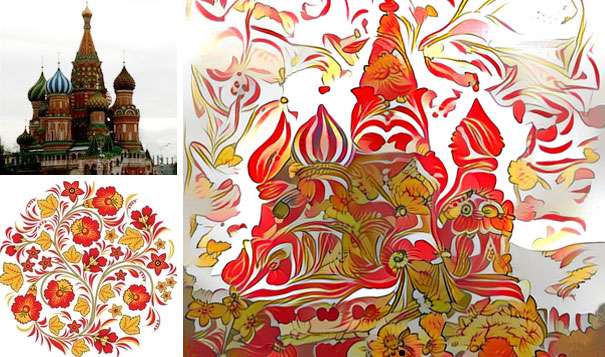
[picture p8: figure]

Figure 1.7: This example of a picture (right) created by an artificial neural network based on two input images (left) illustrates, that by understanding and combining the conceptual elements of a data structure (in this case: an image), new creative

data representations can be formed. Image source: https://www.boredpanda.com/inceptionism-

neural-network-deep-dream-art/?media_id=419452

Figure 1.6: This figure from (Lee, Grosse, Ranganath, & Ng, 2009) depicts the features learned by so called convolutional neural networks, which have been trained on images of faces, cars, elephants, chairs, and a combination of faces, cars, airplanes and motorbikes, respectively. The first row shows the features learned by the neurons of an early layer of the network, the second row those of a later layer. It can be seen, that convolutional neural networks can learn hierarchical representations of images, i. e. identify common local patterns in the data (e. g. eyes or noses in the case of faces), as well as combinations of these, in order to classify before unseen pictures into one of the categories.

### 1.6 Sleep and dream research and artificial intelligence

Several ways can be thought of, how artificial intelligence and machine learning can be used in the field of sleep and dream research. And also vice versa, AI can benefit from the knowledge created by sleep and dream researchers. In fact, research in both directions has been conducted already, as the following non conclusive list shows:
- By studying the nightly brain, mechanisms can be identified, which could lead to significant improvement of artificial neural networks, e. g. as used for unsupervised neural networks in (Hinton, Dayan, Frey, & Neal, 1995) or, regarding the function of sleep for memory consolidation processes or for restructuring knowledge, by (Walker & Russo, 2004). In these cases, artificial neural networks were trained in a similar way like natural neural networks learn, increasing their performance.
- Expert systems have been developed, which aid physicians in diagnosing sleep disorders (Ohayon, Guilleminault, Zulley, Palombini, & Raab, 1999), as well as astronauts in recording sleep data (Callini, Essig, Heher, & Young, 2000).
- Numerous approaches to AI-driven sleep stage classification using machine learning exist, which use as different AI methods such as linear discriminant analysis (Fell, Röschke, Mann, & Schäffner, 1996; Kayikcioglu, Maleki, & Eroglu, 2015), artificial neural networks (Hsu, Yang, Wang, & Hsu, 2013; Oropesa, Cycon, & Jobert, 1999; Park, Pa, & Jmn, 2000; Robert, Guilpin, & Limoge, 1998), support vector machines (Crisler, Morrissey, Anch, & Barnett, 2008; Koley & Dey, 2012; Lajnef et al., 2015), or genetic algorithms combined with a rule-based expert system (Kim & Park, 2000).
- AI methods were also found useful for automatically detecting microstructures in the sleep recordings, e. g. sleep spindles (Schimicek, Zeitlhofer, Anderer, & Saletu, 1994; Sinha, 2008; Ventouras et al., 2012; Wallant, Maquet, & Phillips, 2016).
- Furthermore, even approaches to measure the sleep quality in real-time based on AI-driven analysis of the ECG signal using support vector machines exist (Bsoul, Minn, Nourani, Gupta, & Tamil, 2010).
- Lastly, AI-driven approaches are also used for sleep medical purposes, e. g. for detecting sleep apnea in ECG sleep recordings (Babaeizadeh, White, Pittman, & Zhou, 2010).

No attempt could be found to automate complex sleep laboratory studies in the field, in order to enable naive crowd subjects to conduct them on their own in the field. Most likely, this is due to the unavailability of suited polysomnographic recording devices. As seen in chapter 1.4.2 Field studies using electronic tools, tools which give access to raw data, which are cheap enough for crowd experiments, and which have been shown to have a good polysomnographic data quality are not available on the market. Logically, as long as there is no suited hardware, it makes no sense to develop specialized software, which enables naive crowd subjects to conduct polysomnographic experiments on their own and which uses a machine learning based approach for real-time sleep staging and other experiment control.
In order to change this, two things need to be developed for crowd-based polysomnographic sleep and dream experiments:
- a polysomnographic recording device, which is cheap, easy to use, has real-time raw data access, and which makes interactive sleep experiments in a sleep laboratory fashion possible at the subject’s home,
- a piece of software, which enables naive crowd subjects to conduct the sleep and dream experiments on their own at home, i. e. which instructs the subject and which takes over the experiment control when the subject is asleep using state-of-the-art machine learning algorithms.

### 1.7 Aim of this dissertation

The aim of this dissertation is to develop and to evaluate such a portable sleep and dream experiment system consisting of hardware and software, which enables a crowd of naive subjects to conduct complex polysomnographic experiments at home. In other words, the goal is to make automated, interactive, crowd-based polysomnographic sleep and dream experiments possible. The name of this new system will be the Traumschreiber system (from German words “Traum” (dream) and “Schreiber” (writer)).
In order to test the suitability of the Traumschreiber system for complex crowd-based automated polysomnographic sleep and dream experiments, it will be evaluated regarding its data quality in comparison to sleep laboratory polysomnography, its usability, its production process and production costs, and its overall applicability for this type of studies.

## 2 Methods

### 2.1 Overview

An iteration based approach was chosen for developing the Traumschreiber system. This means that the system was repeatedly improved and tested, until the point was reach, at which a prototype was ready to be evaluated in a sleep laboratory and in field studies. In this chapter, the methods of the development process are described first, and afterwards the methods of the evaluation of the Traumschreiber system are presented.

### 2.2 Development

### 2.2.1 Defining the requirements towards the Traumschreiber system

Based on the experiences from own sleep laboratory and field studies, it was first defined, what the new Traumschreiber system had be able to do in order to fulfill its main purpose – i. e. enabling complex crowd-based automated sleep and dream experiments, including polysomnographic recording of EEG, EOG, EMG and ECG with good data quality, and real-time stimulation of the sleep. The requirements were regularly updated based on the testing during development, and based on the feedback obtained at conferences or of researchers, who tried out the Traumschreiber system (see chapter 2.2.2 Iteration-based development).
The Traumschreiber system was designed to consist of
- a Traumschreiber sleep mask, which is worn by the experiment subject during the night, and which records and stimulates the subject’s sleep,
- a Traumschreiber experiment station, which is placed next to the subject’s bed, and which assists the subject, e. g. gives instructions and analyzes the recorded data in real-time,
- a Traumschreiber data analysis software package, which enables the researcher to perform the most important analysis steps in a standardized way after the data are recorded. Further details are depicted in the figures 2.1, 2.2 and 2.3¹³ for each part.

13 The mind maps were created using the open-source WiseMapping tool.

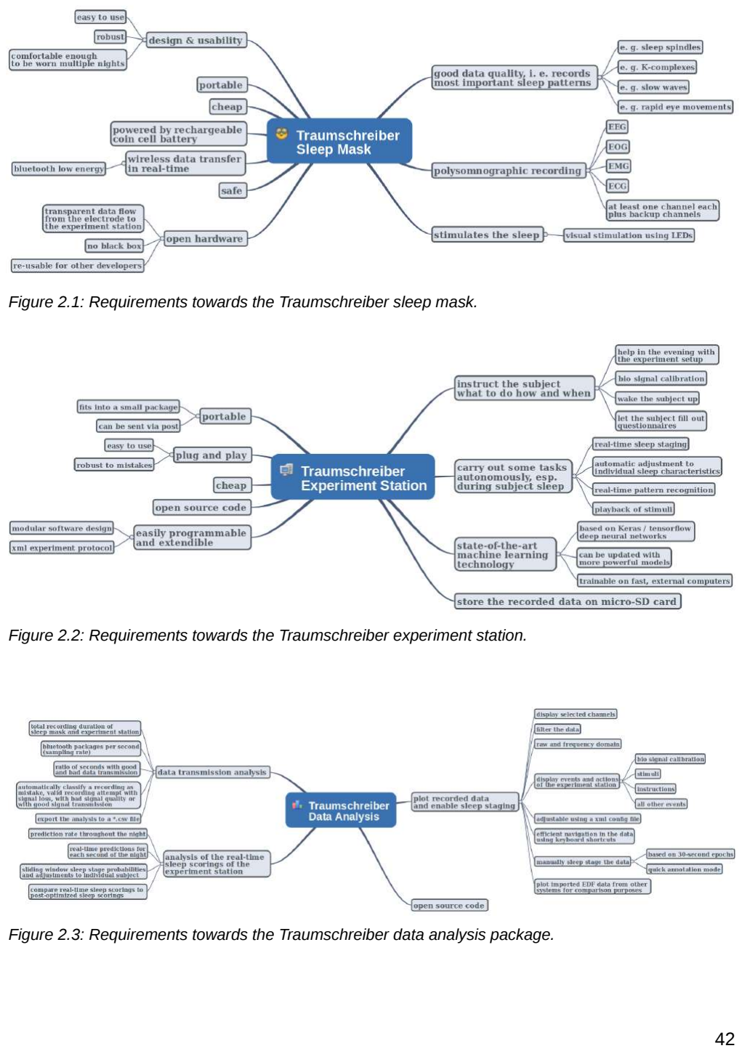
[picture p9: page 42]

Figure 2.3: Requirements towards the Traumschreiber data analysis package.

Figure 2.2: Requirements towards the Traumschreiber experiment station.

Figure 2.1: Requirements towards the Traumschreiber sleep mask.

### 2.2.2 Iteration-based development

During development, several decisions had to be made, how to best achieve the features depicted above. Should multi-usable conductive cloth be used as an electrode material, single use sticky electrodes, cup electrodes, a standard EEG cap, or some sort of a plastic helmet? How many channels are necessary for recording sleep physiological data; should there be backup channels in case some channels have a bad signal? How shall the data be transferred between the sleep recording device and the experiment station: via wi-fi, bluetooth, or bluetooth low energy? Should the experiment station rather be a Raspberry Pi minicomputer, a smartphone, or directly integrated into the sleep mask? Should acoustic stimuli and instructions be delivered to the subject via speakers or headphones? Should the recorded data be processed locally, or directly transferred to a server via internet? In what kind of format should the data be stored? Which programming language should be used for programming the experiment station? Which frameworks are suited best for implementing the artificial intelligence part of the system? Not even mentioning all the electric engineering decisions, e. g. regarding the hardware filters, the placement of the components on the PCB, the selection of the optimal microcontroller considering costs, energy consumption, availability, price, and of course technical properties (speed, ADC, connection types, etc.), and many more – in the end, a complete EEG was constructed from scratch. And where should this be produced (China, Germany)? How should it be financed?
These questions illustrate well, how many different decisions had to be made during development, ranging from textile design, to electric engineering, to machine learning, to sleep and dream research. Trying to answer all questions at once right in the beginning of the project was not possible. Instead, an iteration-based approach was chosen.
Each iteration consisted of four main steps:
1. Defining / adjusting the requirements towards the new version of the system, and setting priorities. On the one hand, this was based on the experiences gained from testing the previous version in self-experiments. On the other hand, input from other sleep researchers and clinicians was obtained. Some of these researchers tried out prototypes of the system, others gave feedback at oral or poster presentations about the system at scientific conferences¹⁴. Furthermore, interested hobbyists

14 23rd Annual Meeting of the German Sleep Society 2015 - oral presentation at the young scientists

(mostly lucid dreaming enthusiasts experienced with other consumer devices such as the Zeo) suggested features to be included in the next development cycle. Last, but not least, the experiences of the author of this dissertation from the sleep experiments at the Osnabrueck University sleep laboratory and at the Max Planck Institute of Psychiatry, Munich, inspired the development of new features, and helped setting the priorities.
2. Finding ways, how to implement the needed features, or how to improve the existing solution. This depended strongly on the type of task, which was conducted, and was done via internet research (e. g. finding new electric components), trial and error (e. g. trying out different approaches to make the sleep mask more comfortable), measuring and electrical engineering using an oscilloscope, by-hand calculations and specialized software (e. g. designing hardware filters, drafting the electrical circuit diagrams and PCB layouts), programming and refactoring (e. g. new software features or the microcontroller code), and group discussions (e. g. which tasks should have priorities or whether to choose a more expensive but
better | electrical
component | or | not).
Furthermore, | the
autodidactic | learning
part should not be
underestimated, as no
professional | electrical
engineer | or | product
designer was involved in
the development, and
most | skills | were
obtained in a self-taught
way.

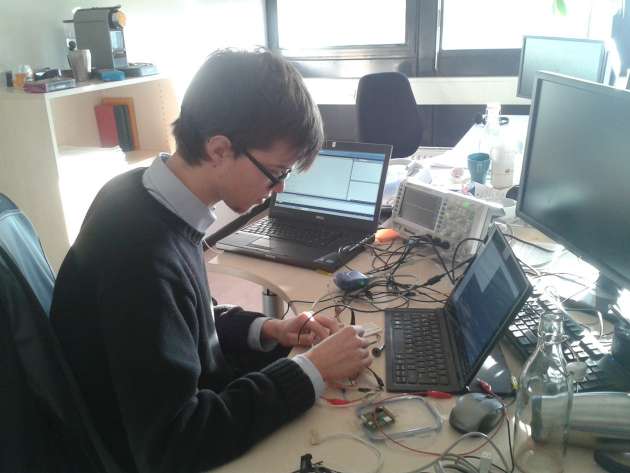
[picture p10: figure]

workshop: “The Traumschreiber Project”; Hofgeismar Young Scientists Workshop of the German Sleep Society 2016 - oral presentation: “Updates on the Traumschreiber Project”; MetaRheinMainChaosDays 2016 of the Chaos Computer Club - oral presentation: “Traumschreiber: Eine Open Source Schlafmaske, die Hirnaktivitäten messen und beeinflussen kann”; 23rd Congress of the European Sleep Research Society 2016 - poster presentation P214: “‘Traumschreiber’: measuring and manipulating human sleep with a portable high-quality but low-cost polysomnographic system”.

Figure 2.4: Picture of the technical development process (Johannes Leugering)

3. Obtaining finances for the production of the new prototype. In the beginning, the Neuroinformatics department of Osnabrueck University funded the project, as well as the Institute of Cognitive Science at Osnabrueck University. In later development stages, when the production became more and more expensive, also external financial sources had to be acquired, e. g. the Hans-Mühlenhoff-Stiftung Osnabrueck (2,000 EUR) and the German Sleep Society (5,000 EUR).
4. Producing a new prototype based on the current iteration’s developments, and testing it. In the very beginning of the project, the electric parts of the sleep recording device were soldered on a breadboard and directly tested. In subsequent development stages, the printed circuit board was designed in Osnabrueck, produced in a factory in Germany, and assembled with the electric components in Osnabrueck, as well as tested in Osnabrueck. During the last three developments iterations, the printed circuit board was designed in Osnabrueck, produced and assembled at much lower costs in China, then imported to Germany, and tested in Osnabrueck. The textile parts were completely self-designed in the very beginning. Later, ready-to-use sleep masks were bought in Germany and processed further in Osnabrueck, and finally much cheaper (and at the same time even more comfortable) sleep masks were imported from China and processed further in Osnabrueck, i. e. working the electric parts into the sleep masks. Testing consisted of a) wearing the device during self-recordings for several nights and then analyzing the data quality by plotting and visual inspection, b) analyzing the comfort of the sleep recording device, and c) analyzing the necessary work steps for an experimenter to conduct an experiment. If the new features of the system worked well, they were kept for the next development iteration, if not, they were either changed or removed in the next development round.
During all the above mentioned work steps, external advice or work force was acquired – in some development iterations for the one step, in other iterations for another step. For the textile development, for example, a cooperation with the study program “Textile design” at Osnabrueck University was established, and cognitive science and textile design students drafted and produced several textile designs, how high-tech sleep masks should look like. Moreover, some work packages have been “outsourced” to bachelor’s theses of cognitive science students, supervised by the author of this dissertation (all attached in the online appendix): a literature review of sleep stimulation experiments (Braumann, 2016), testing the EOG capabilities of the sleep recording device (Laubisch, 2016), conducting a sleep laboratory validation (Nienhaus, 2017), testing the usability and functionality of the system (Mandt, 2017), and programming a first version of an Android app (Jäkel, 2017).
# | Features, comments | Date | Production place

v0.0 | Breadboard based EOG measurement with oscilloscope, inspired by OpenEEG project | 07/2014 to 09/2014 | At home
v0.1 | First PCB, measures EOG and transmits the signal via cable to computer | 10/2014 to 07/2015 | PCB: produced in German factory, equipped by hand in Osnabrueck
v0.2 | Measures sleep EEG, transmits the signal via bluetooth 2.0, has LEDs on external board, which can be controlled via bluetooth, limited auditory stimulation via headphone plug onboard | 08/2015 to 11/2015 | PCB produced in German factory, equipped by hand in Osnabrueck
v1.0 | Uses self-designed signal amplifiers (op-amps instead of IAs), LED board split up into driver board and satellite LED boards, used during textile design seminar | 12/2015 to 03/2016 | PCB produced in German factory, equipped by hand in Osnabrueck
v2.2 | BLE implemented (but does not work), eight channels instead of four, uses IAs again for signal amplification, has flat connectors for the cables, first field study | 04/2016 to 12/2016 | PCB produced and equipped in China
v2.4 | BLE works, LED onboard, battery onboard, DIN cable connectors, sleep laboratory validation, most boards faulty due to bad production quality of new Chinese manufacturer | 12/2016 to 03/2017 | PCB produced and equipped in China
v2.5 | Slightly changed LEDs, ordered at first Chinese manufacturer again (good production quality) Final version | 03/2017 to 08/2017 | PCB produced and equipped in China

Table 2.1: Overview of the main electric development iterations

In total, seven development iterations were conducted. Especially obtaining the finances (by applying for small grants), university and customs bureaucracy, production abroad and testing in experiments were very time consuming. The final version of the system (including the sleep recording device), as well as the exact work steps, how to produce it, are described in chapter 3.1 Development and 3.2.3 Third study: Preparing polysomnographic crowd experiments.

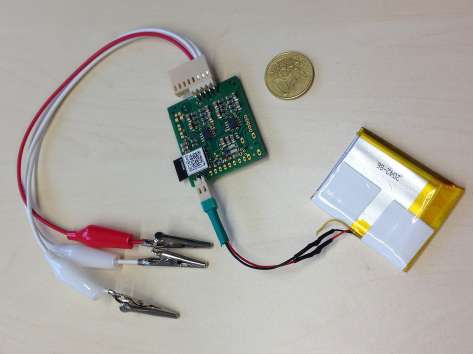
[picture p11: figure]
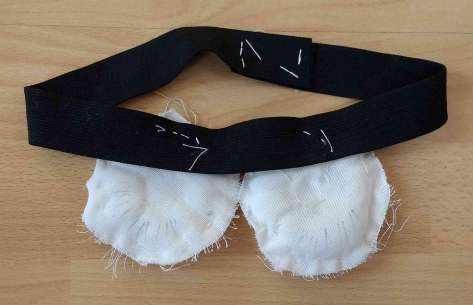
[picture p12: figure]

Figure 2.7: One intermediate result of the textile development process.

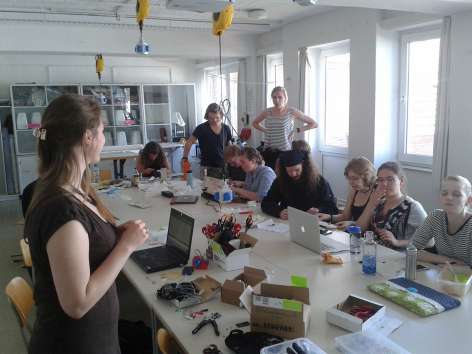
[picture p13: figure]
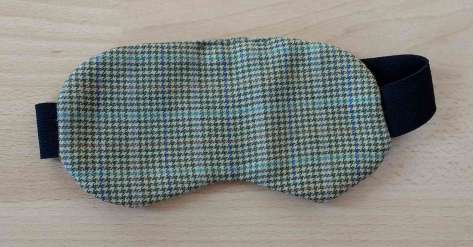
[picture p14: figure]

Figure 2.8: The first self-made prototype of the textile part of the sleep mask. Note that it is flat,
i. e. moving the (closed) eyes under this sleep mask is uncomfortable.

Figure 2.5: Electric prototype version 0.2. It had Figure 2.6: Picture of the textile design seminar. to be connected to an external battery, it had
only four data channels and used bluetooth 2.0
instead of BLE for data transmission.

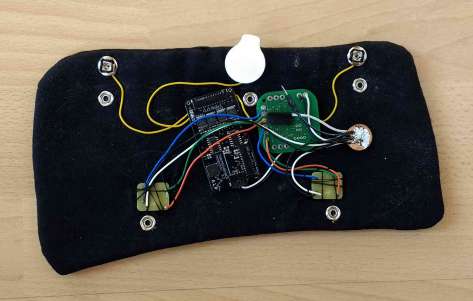
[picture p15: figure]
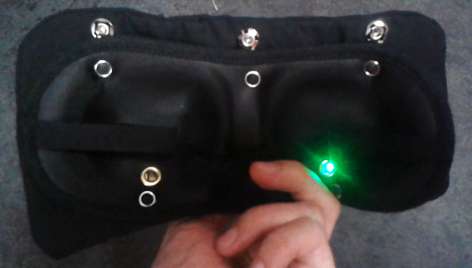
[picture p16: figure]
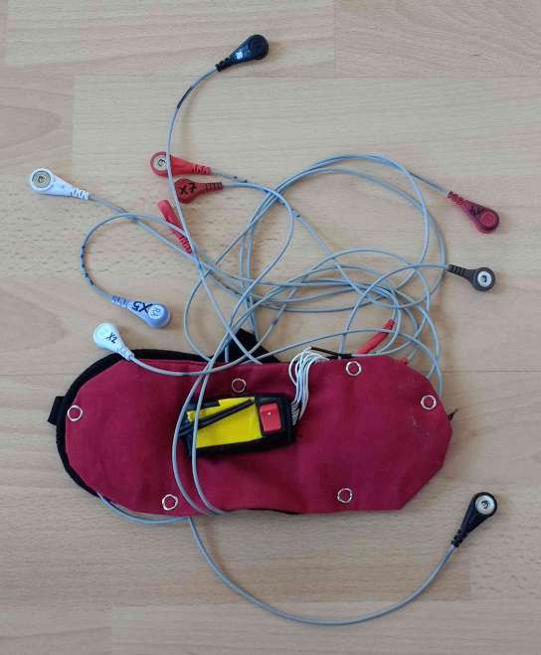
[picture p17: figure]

Figure 2.11: Traumschreiber sleep mask version 2.2. Note that the cables are far too long (making the sleep mask heavy and uncomfortable) and that the electronics are not hidden inside the mask.

Figure 2.10: Traumschreiber sleep mask 1.0 together with the eye cover. Note that the light of the right LED shines through the eyelet.

Figure 2.9: Traumschreiber sleep mask version
1.0. Note the several boards for measuring sleep, for LED control and the actual LEDs, all connected via cables.

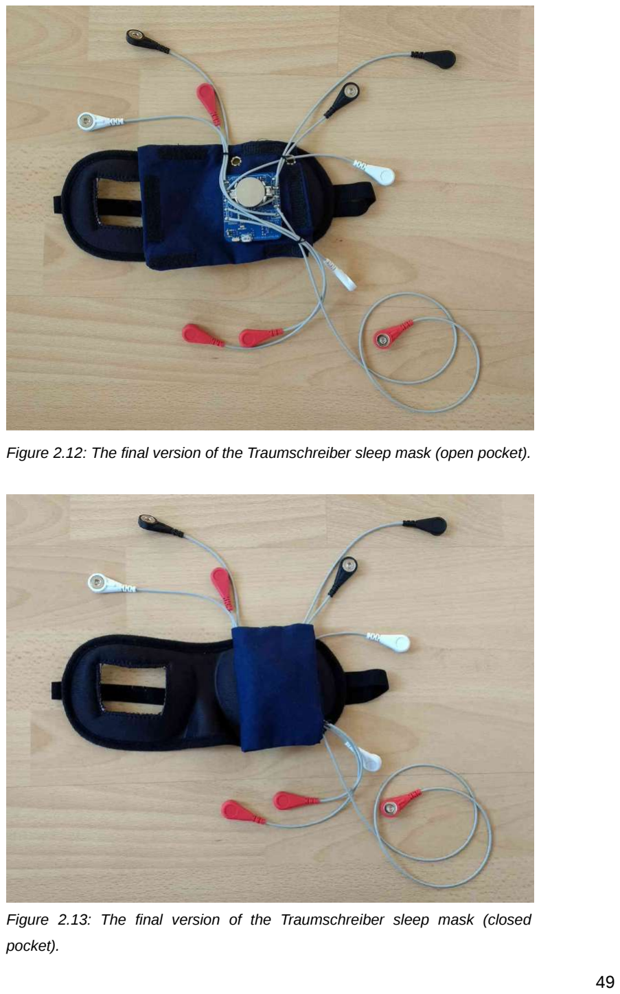
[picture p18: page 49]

Figure 2.12: The final version of the Traumschreiber sleep mask (open pocket).

Figure 2.13: The final version of the Traumschreiber sleep mask (closed pocket).

### 2.3 Evaluation

After developing the system, it was evaluated in several studies. The purpose of this was to analyze, how well the system is suited for real-world usage of sleep researchers. It is suggested to first read the description of the development results (chapter 3.1 Development) before continuing with reading this chapter.

### 2.3.1 First study: Sleep laboratory validation

2.3.1.1 Aim

Can the same sleep characteristics be measured using the Traumschreiber system and a commercially available, worldwide used medical polysomnographic system? What are the differences in the recorded data? In order to answer these questions, the Traumschreiber system was validated against such a commercial medical polysomnographic system in the sleep laboratory of Osnabrueck University.¹⁵

2.3.1.2 Subjects

Seven healthy students (2 female, age between 18 and 27 years) were recruited via email announcement. Exclusion criteria were: younger than 18 years; pregnancy or breastfeeing; suffering from psychic or psychosomatic illnesses, neurologic diseases, hallucinations, or sleep disorders (evaluated using the standardized LISST questionnaire (Schürmann et al., 2001)); taking sleep drugs, psychotropic drugs, pain killers, or antihistaminics. The subjects were asked to not consume any alcohol within the last 24 hours before the experiment, to not nap during the day, and to sleep regularly the night before the experiment. The subjects spent one night each at the Osnabrueck University sleep laboratory. They signed written informed consent and were compensated with 3 subject hours, which they needed for their degree. One subject had to be excluded from data analysis, as the battery of the sleep mask was not charged and recorded only a part of the night.

2.3.1.3 Materials and procedure

Using an ALICE 3.5 commercial medical polysomnographic system, chin EMG, EOG, frontal, central and occipital EEG (2 channels each) as well as ECG were recorded using

15 The study was conducted together with Frederik Nienhaus, who wrote his bachelor’s thesis about this experiment (Nienhaus, 2017, supervised by the author of this dissertation).

gold cup electrodes (central and occipital EEG) and single use sticky electrodes (Covidien Kendall H135SG) for the other recording locations. Simultaneously, the prototype version 2.4 of the Traumschreiber system was used, which did not differ from the final version of the Traumschreiber system regarding the relevant technical specifications of the PCB or its components (same filters, same microprocessor, same bluetooth chip, etc.). The electrodes of the Traumschreiber sleep mask were of the same type as the ALICE system’s and were attached directly next to them, with the intention to record similar physiological activity. An exception were the central and occipital EEG electrodes of the ALICE system: Since only single use sticky electrodes are used in the standard Traumschreiber recording setup, which do not hold in hair, no Traumschreiber electrodes were attached near them. Thus, in total 14 electrodes were fixed in the face of the subjects, plus additional 11 electrodes behind the ears (references), in the hair (EEG), and on the chest (ECG) – see figure 2.14.
The subjects were sent to bed around 11 PM, and were woken up around 7 AM, resulting in a total of 8 hours of bed time.

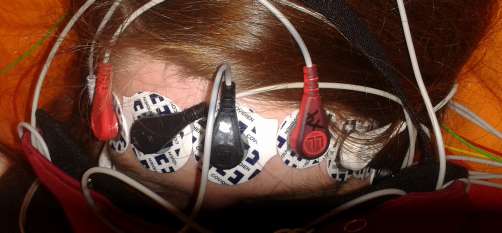
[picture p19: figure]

2.3.1.4 Data analysis

30-second epochs of the data were plotted in 15 minute intervals using the
post_visualization.py | script | of | the
Traumschreiber data analysis software package and a modified EDF-compatible
version of it for the ALICE data. This
means that a snapshot of the recorded
data was produced for each of the time points 11:00 PM, 11:15 PM, 11:30 PM throughout the whole night to 6:30 AM, 6:45 AM, 7:00 AM for both systems including all channels. Both systems were synchronized in time using the bio signal calibration markers, i. e. the calibration procedure at the beginning of each night, for example clenching the teeth or moving the eyes in a systematic manner.
The plots of the data of the Traumschreiber system and of the ALICE system were then compared by visual inspection. As a first step, each plot of the Traumschreiber system was analyzed, whether there were clearly recognizable slow waves, sleep spindles, K-

Figure 2.14: Sticky electrodes of both systems were placed on the forehead, recording EOG and frontal EEG.

complexes, a low amplitude and mixed frequency EEG signal, rapid eye movements, slow eye movements, eye blinks, clearly visible heart beats in the ECG signal, arousals, alpha waves, or vertex waves. Next, the same was done for the plots of the ALICE system. It was then denoted, whether the two systems showed similar elements in each corresponding epoch, or whether some graphoelements could only be seen in one of the recordings. Furthermore, the differences were described in detail by words, if necessary, e.
g. if sleep spindles were not detectable in the Traumschreiber system’s plot, because they were of central origin. As a second step, every epoch of each system was classified into the categories wake, REM, N2, N3 and ambivalent sleep. It is sometimes impossible to rate, whether a single 30-second data bin depicts wake, N1, N2 or (tonic) REM sleep, because this depends on the classifications of previous epochs, too. For these cases, the ambivalent sleep category was used. The classifications of both systems were then compared. Descriptive statistics were used to summarize the results.
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

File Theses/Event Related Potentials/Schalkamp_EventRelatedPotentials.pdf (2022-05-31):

## University of Osnabr¨uck

# Analyzing event-related potentials in 8-channel EEG data using machine learning methods

# Ann-Kathrin Schalkamp

963930

# A thesis presented for the degree of Bachelor of Science

First Supervisor: Olivera Stojanovic, M.Sc.

## Second Supervisor: Prof. Dr. Gordon Pipa

26.09.2018

## Abstract

Over the past few years Brain Computer Interface (BCI) research programs have arisen searching for a new channel of non-muscular communication with the external world. One possible channel can be provided via electroencephalography (EEG) systems, which probe the electric potential on the scalp with electrodes. EEG systems are becoming cheaper, portable versions are developed, and such systems are often used as the recording system for BCIs. In this study a recently developed portable high-tech sleep mask, the Traumschreiber, was used to record ERPs. The placement of the electrodes was performed in a different way compared to standard EEG systems. After re-referencing only one recording electrode but several references produced data for eight channels. Different combinations of the data were used for training logistic regression models (single channel, best three channels to increase dimensionality, best three channels to increase training set). Those were evaluated based on their predictive performance by using the area under the curve (AUC) as a metric. As a further analysis the data of subjects was combined and compared to the results of the subject specific analysis and the traditional averaging method.
In this study the usage of the single best channel resulted in the best prediction performance ( 0.74 for SSVEP, 0.7 for MP, 0.76 for N240 targets and 0.76 for N240 distractors). Combining data of several channels, that use the same recording electrode to increase the amount of data produced good results regardless of the task’s complexity (0.72 for SSVEP, 0.66 for MP, 0.76 for N240 targets and 0.76 for N240 distractors). For the data of low-level tasks the combination of several subjects proved to be an option to increase the training data as well (0.73 for SSVEP and 0.66 for MP).

## List of Figures

1.1 Logistic Function | | 6
2.1 Used version of Traumschreiber | | 9
2.2 EasyCap with used electrode placement | | 10
2.3 Subject with setup | | 12
2.4 Liveplot during channel adjustment | | 12
2.5 Channels after re-referencing to electrode four | | 14
2.6 Before and After Re-referencing | | 15
2.7 Before and After Artifact Removal | | 17
2.8 Before and After Baseline Correction | | 18
3.1 SSVEP: variance across subjects | | 20
3.2 SSVEP: Averaging | | 21
3.3 SSVEP: Comparison of methods | | 23
3.4 SSVEP: Comparison Averaging Logistic Regression Coefficients | | 24
3.5 MP: Averaging | | 25
3.6 MP: Comparison of methods | | 27
3.7 MP: Comparison Averaging Logistic Regression Coefficients | | 28
3.8 N240: grand average | | 29
3.9 N240 target: Averaging | | 30
3.10 N240 distractor: Averaging | | 31
3.11 N240 target: Comparison of methods | | 33
3.12 N240 target: Comparison Averaging Logistic Regression Coefficients | | 34
3.13 N240 distractor: Comparison of methods | | 35
3.14 N240 distractor: Comparison Averaging Logistic Regression Coefficients . . . | 36
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

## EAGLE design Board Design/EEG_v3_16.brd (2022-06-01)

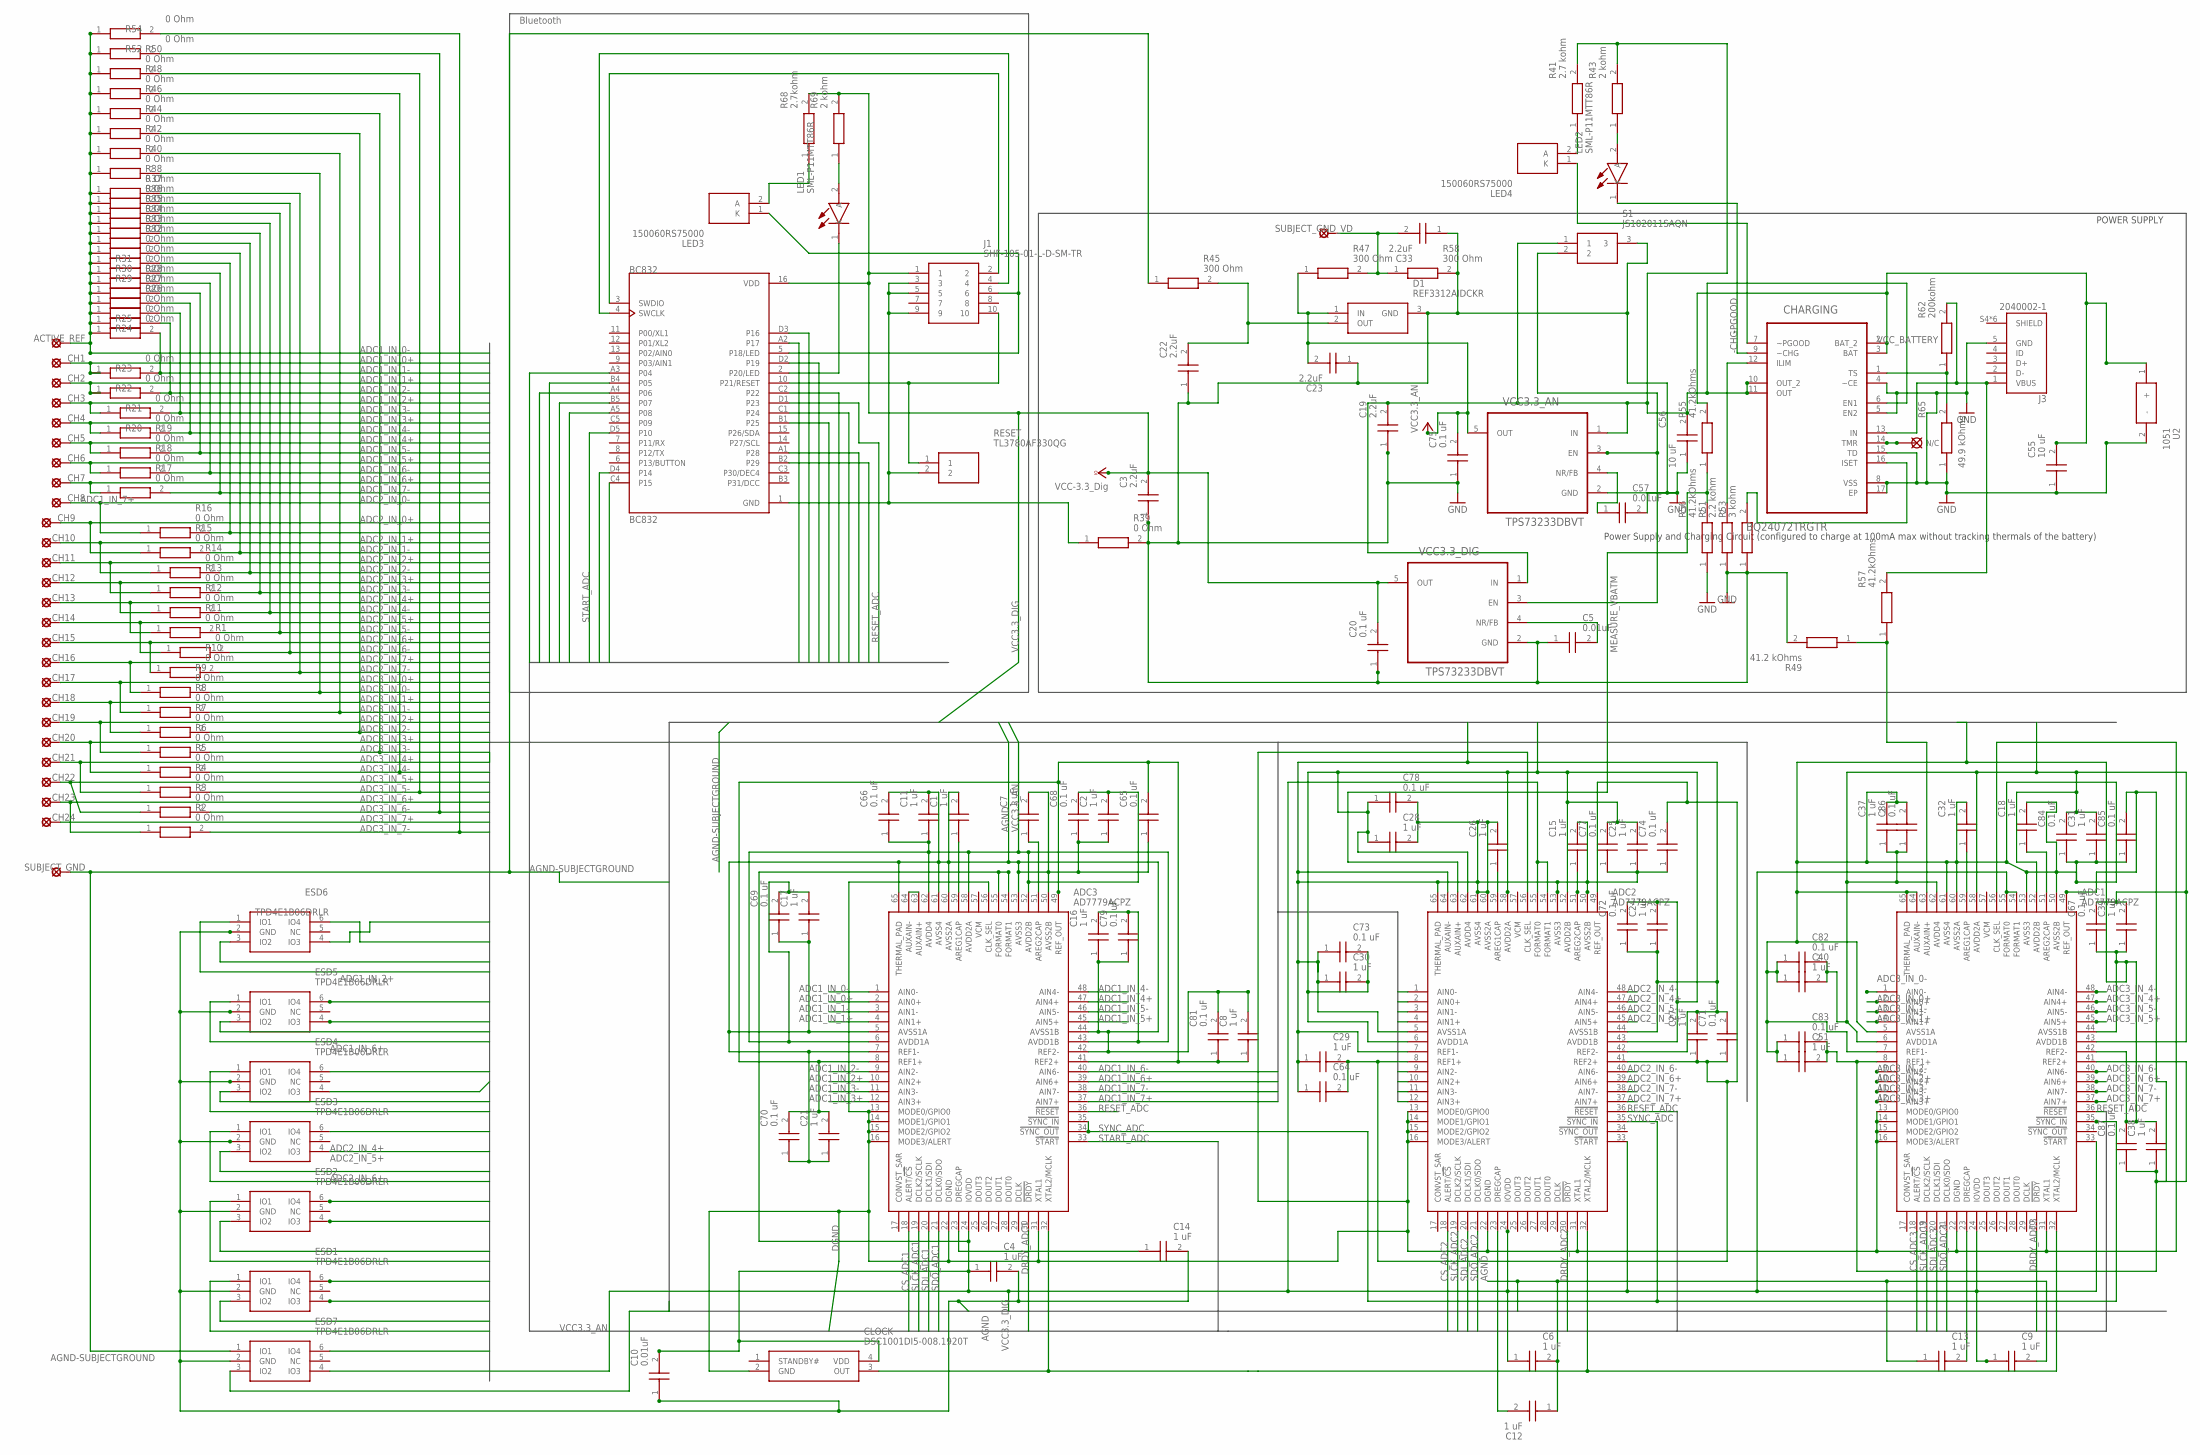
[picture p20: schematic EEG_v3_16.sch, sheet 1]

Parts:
ACTIVE_REF: SE11
ADC1, ADC2, ADC3: AD7779ACPZ; QFN50P900X900X80-65N
BC832: BC832; XCVR_BC832
C1, C2, C4, C6, C7, C8, C9, C11, C12, C13, C14, C15, C16, C17, C18, C21, C24, C25, C26, C27, C28, C29, C30, C31, C32, C37, C38, C39, C40, C51: 1 uF; CAPC1005X33N
C3, C19, C22, C23, C33: 2.2uF; CAPC0603X33N
C5, C10, C57: 0.01uF; CAPC0603X33N
C20, C64, C65, C66, C67, C68, C69, C70, C71, C72, C73, C74, C75, C77, C78, C79, C81, C82, C83, C84, C85, C86, C87: 0.1 uF; CAPC0603X33N
C55, C56: 10 uF; CAPC1608X100N
CH1, CH2, CH3, CH4, CH5, CH6, CH7, CH8, CH9, CH10, CH11, CH12, CH13, CH14, CH15, CH16, CH17, CH18, CH19, CH20, CH21, CH22, CH23, CH24: SE11
CHARGING: BQ24072TRGTR; QFN50P300X300X100-17N
CLOCK: DSC1001DI5-008.1920T; DSC1001DI50081920T
D1: REF3312AIDCKR; SOT65P210X110-3N
ESD1, ESD2, ESD3, ESD4, ESD5, ESD6, ESD7: TPD4E1B06DRLR; SOP50P160X60-6N
J1: SHF-105-01-L-D-SM-TR; SHF-105-01-X-D-SM-TR
J3: 2040002-1; TE_2040002-1
LED1, LED2: SML-P11MTT86R; LEDC1006X25N
LED3, LED4: 150060RS75000; LEDC1608X80N
R1, R2, R3, R4, R5, R6, R7, R8, R9, R10, R11, R12, R13, R14, R15, R16, R17, R18, R19, R20, R21, R22, R23, R24, R25, R26, R27, R28, R29, R30, R31, R32, R33, R34, R35, R36, R37, R38, R39, R40, R42, R44, R46, R48, R50, R52, R54: 0 Ohm; RESC1608X55N
R41: 2.7 kohm; RESC0603X26N
R43, R69: 2 kohm; RESC0603X26N
R45, R47, R58: 300 Ohm; RESC0603X26N
R49: 41.2 kOhms; RESC0603X28N
R51: 2.2 kohm; RESC0603X28N
R53: 3 kohm; RESC0603X26N
R55, R56, R57: 41.2kOhms; RESC0603X28N
R62: 200kohm; RESC0603X28N
R65: 49.9 kOhms; RESC0603X28N
R68: 2.7kohm; RESC0603X26N
RESET: TL3780AF330QG
S1: JS102011SAQN
SUBJECT_GND: SE11
SUBJECT_GND_VD: SE11
U2: 1051
VCC3.3_AN, VCC3.3_DIG: TPS73233DBVT; SOT95P280X145-5N

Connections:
-CHG: CHARGING.9 (~CHG), LED2.1 (K)
-PGOOD: CHARGING.7 (~PGOOD), LED4.1 (K)
ADC1_IN_0+: ADC3.2 (AIN0+), CH1.MP, ESD6.4 (IO3), R23.1
ADC1_IN_0-: ACTIVE_REF.MP, ADC3.1 (AIN0-), ESD6.6 (IO4), R24.1, R25.1, R26.1, R27.1, R28.1, R29.1, R30.1, R31.1, R32.1, R33.1, R34.1, R35.1, R36.1, R37.1, R38.1, R40.1, R42.1, R44.1, R46.1, R48.1, R50.1, R52.1, R54.1
ADC1_IN_1+: ADC3.4 (AIN1+), CH2.MP, ESD6.3 (IO2), R22.1
ADC1_IN_1-: ADC3.3 (AIN1-), R23.2, R24.2
ADC1_IN_2+: ADC3.10 (AIN2+), CH3.MP, ESD6.1 (IO1), R21.1
ADC1_IN_2-: ADC3.9 (AIN2-), R22.2, R25.2
ADC1_IN_3+: ADC3.12 (AIN3+), CH4.MP, ESD5.6 (IO4), R20.1
ADC1_IN_3-: ADC3.11 (AIN3-), R21.2, R26.2
ADC1_IN_4+: ADC3.47 (AIN4+), CH5.MP, ESD5.4 (IO3), R19.1
ADC1_IN_4-: ADC3.48 (AIN4-), R20.2, R27.2
ADC1_IN_5+: ADC3.45 (AIN5+), CH6.MP, ESD5.3 (IO2), R18.1
ADC1_IN_5-: ADC3.46 (AIN5-), R19.2, R28.2
ADC1_IN_6+: ADC3.39 (AIN6+), CH7.MP, ESD5.1 (IO1), R17.1
ADC1_IN_6-: ADC3.40 (AIN6-), R18.2, R29.2
ADC1_IN_7+: ADC3.37 (AIN7+), CH8.MP, ESD4.6 (IO4), R16.1
ADC1_IN_7-: ADC3.38 (AIN7-), R17.2, R30.2
ADC2_IN_0+: ADC2.2 (AIN0+), CH9.MP, ESD4.4 (IO3), R15.1
ADC2_IN_0-: ADC2.1 (AIN0-), R16.2, R31.2
ADC2_IN_1+: ADC2.4 (AIN1+), CH10.MP, ESD4.3 (IO2), R14.1
ADC2_IN_1-: ADC2.3 (AIN1-), R15.2, R32.2
ADC2_IN_2+: ADC2.10 (AIN2+), CH11.MP, ESD4.1 (IO1), R13.1
ADC2_IN_2-: ADC2.9 (AIN2-), R14.2, R33.2
ADC2_IN_3+: ADC2.12 (AIN3+), CH12.MP, ESD3.6 (IO4), R12.1
ADC2_IN_3-: ADC2.11 (AIN3-), R13.2, R34.2
ADC2_IN_4+: ADC2.47 (AIN4+), CH13.MP, ESD3.4 (IO3), R11.1
ADC2_IN_4-: ADC2.48 (AIN4-), R12.2, R35.2
ADC2_IN_5+: ADC2.45 (AIN5+), CH14.MP, ESD3.3 (IO2), R1.1
ADC2_IN_5-: ADC2.46 (AIN5-), R11.2, R36.2
ADC2_IN_6+: ADC2.39 (AIN6+), CH15.MP, ESD3.1 (IO1), R10.1
ADC2_IN_6-: ADC2.40 (AIN6-), R1.2, R37.2
ADC2_IN_7+: ADC2.37 (AIN7+), CH16.MP, ESD2.6 (IO4), R9.1
ADC2_IN_7-: ADC2.38 (AIN7-), R10.2, R38.2
ADC3_IN_0+: ADC1.2 (AIN0+), CH17.MP, ESD2.4 (IO3), R8.1
ADC3_IN_0-: ADC1.1 (AIN0-), R9.2, R40.2
ADC3_IN_1+: ADC1.4 (AIN1+), CH18.MP, ESD2.3 (IO2), R7.1
ADC3_IN_1-: ADC1.3 (AIN1-), R8.2, R42.2
ADC3_IN_2+: ADC1.10 (AIN2+), CH19.MP, ESD2.1 (IO1), R6.1
ADC3_IN_2-: ADC1.9 (AIN2-), R7.2, R44.2
ADC3_IN_3+: ADC1.12 (AIN3+), CH20.MP, ESD1.6 (IO4), R5.1
ADC3_IN_3-: ADC1.11 (AIN3-), R6.2, R46.2
ADC3_IN_4+: ADC1.47 (AIN4+), CH21.MP, ESD1.4 (IO3), R4.1
ADC3_IN_4-: ADC1.48 (AIN4-), R5.2, R48.2
ADC3_IN_5+: ADC1.45 (AIN5+), CH22.MP, ESD1.3 (IO2), R3.1
ADC3_IN_5-: ADC1.46 (AIN5-), R4.2, R50.2
ADC3_IN_6+: ADC1.39 (AIN6+), CH23.MP, ESD1.1 (IO1), R2.1
ADC3_IN_6-: ADC1.40 (AIN6-), R3.2, R52.2
ADC3_IN_7+: ADC1.37 (AIN7+), CH24.MP, ESD7.6 (IO4)
ADC3_IN_7-: ADC1.38 (AIN7-), R2.2, R54.2
AGND: ADC1.5 (AVSS1A), ADC1.7 (REF1-), ADC1.42 (REF2-), ADC1.44 (AVSS1B), ADC1.50 (AVSS2B), ADC1.53 (AVSS3), ADC1.60 (AVSS2A), ADC1.61 (AVSS4), ADC1.64 (AUXAIN-), ADC1.65 (THERMAL_PAD), ADC2.5 (AVSS1A), ADC2.7 (REF1-), ADC2.42 (REF2-), ADC2.44 (AVSS1B), ADC2.50 (AVSS2B), ADC2.53 (AVSS3), ADC2.60 (AVSS2A), ADC2.61 (AVSS4), ADC2.64 (AUXAIN-), ADC2.65 (THERMAL_PAD), ADC3.5 (AVSS1A), ADC3.7 (REF1-), ADC3.42 (REF2-), ADC3.44 (AVSS1B), ADC3.50 (AVSS2B), ADC3.53 (AVSS3), ADC3.60 (AVSS2A), ADC3.61 (AVSS4), ADC3.65 (THERMAL_PAD), C1.2, C2.1, C3.1, C4.2, C5.1, C6.2, C7.2, C8.2, C9.2, C10.1, C11.2, C12.1, C13.1, C14.2, C15.2, C16.1, C17.1, C18.2, C19.1, C20.1, C21.1, C22.1, C23.1, C24.1, C25.1, C26.2, C27.2, C28.2, C29.1, C30.1, C31.1, C32.2, C33.1, C37.2, C38.2, C39.1, C40.1, C51.1, C55.1, C56.1, C57.2, C64.1, C65.1, C66.2, C67.1, C68.1, C69.1, C70.1, C71.2, C72.1, C73.1, C74.1, C75.1, C77.1, C78.2, C79.1, C81.2, C82.1, C83.1, C84.1, C85.1, C86.2, C87.2, CHARGING.4 (~CE), CHARGING.5 (EN2), CHARGING.8 (VSS), CHARGING.15 (TD), CHARGING.17 (EP), D1.3 (GND), ESD1.2 (GND), ESD2.2 (GND), ESD3.2 (GND), ESD4.2 (GND), ESD5.2 (GND), ESD6.2 (GND), ESD7.2 (GND), J3.5 (GND), R39.2, R49.2, R51.1, R53.1, R56.1, R58.2, R65.1, S1.3, U2.2 (-), VCC3.3_AN.2 (GND), VCC3.3_DIG.2 (GND)
AGND-SUBJECTGROUND: ESD7.1 (IO1), R45.1, SUBJECT_GND.MP
CS_ADC1: ADC3.18 (ALERT/!CS), BC832.A4 (P06)
CS_ADC2: ADC2.18 (ALERT/!CS), BC832.A5 (P08)
CS_ADC3: ADC1.18 (ALERT/!CS), BC832.C1 (P24)
DGND: ADC1.13 (MODE0/GPIO0), ADC1.14 (MODE1/GPIO1), ADC1.15 (MODE2/GPIO2), ADC1.16 (MODE3/ALERT), ADC1.22 (DGND), ADC1.31 (XTAL1), ADC1.56 (CLK_SEL), ADC2.13 (MODE0/GPIO0), ADC2.14 (MODE1/GPIO1), ADC2.15 (MODE2/GPIO2), ADC2.16 (MODE3/ALERT), ADC2.22 (DGND), ADC2.31 (XTAL1), ADC2.56 (CLK_SEL), ADC3.13 (MODE0/GPIO0), ADC3.14 (MODE1/GPIO1), ADC3.15 (MODE2/GPIO2), ADC3.16 (MODE3/ALERT), ADC3.22 (DGND), ADC3.31 (XTAL1), ADC3.56 (CLK_SEL), BC832.1 (GND), CLOCK.2 (GND), J1.3, J1.5, J1.9, R39.1, RESET.2
DRDY_ADC1: ADC3.30 (!DRDY), BC832.A2 (P17)
DRDY_ADC2: ADC2.30 (!DRDY), BC832.D4 (P14)
DRDY_ADC3: ADC1.30 (!DRDY), BC832.B1 (P25)
MEASURE_VBATM: ADC2.63 (AUXAIN+), R55.1, R56.2
MEASURE_VUSB: ADC1.63 (AUXAIN+), R49.1, R57.1
unnamed: ADC3.59 (AREG1CAP), C1.1
unnamed: ADC2.23 (DREGCAP), C12.2
unnamed: C22.2, D1.2 (OUT), R45.2
unnamed: C5.2, VCC3.3_DIG.4 (NR/FB)
unnamed: BC832.2 (P20/LED), LED1.1 (K)
unnamed: ADC3.63 (AUXAIN+), ADC3.64 (AUXAIN-)
unnamed: ADC3.51 (AREG2CAP), C7.1
unnamed: LED3.2 (A), R68.1
unnamed: LED1.2 (A), R69.1
unnamed: LED4.2 (A), R41.1
unnamed: ADC2.51 (AREG2CAP), C15.1
unnamed: ADC3.23 (DREGCAP), C14.1
unnamed: ADC1.23 (DREGCAP), C13.2
unnamed: LED2.2 (A), R43.1
unnamed: C57.1, VCC3.3_AN.4 (NR/FB)
unnamed: ADC1.59 (AREG1CAP), C32.1
unnamed: ADC2.59 (AREG1CAP), C26.1
unnamed: ADC1.51 (AREG2CAP), C18.1
unnamed: CHARGING.1 (TS), R62.1, R65.2
unnamed: CHARGING.16 (ISET), R53.2
unnamed: CHARGING.12 (ILIM), R51.2
P18/LED: BC832.5 (P18/LED), J1.6, LED3.1 (K)
POWERUP: S1.2, VCC3.3_AN.3 (EN), VCC3.3_DIG.3 (EN)
REF_ADC1: ADC3.8 (REF1+), ADC3.41 (REF2+), ADC3.49 (REF_OUT), C8.1, C21.2, C65.2, C70.2, C81.1
REF_ADC2: ADC2.8 (REF1+), ADC2.41 (REF2+), ADC2.49 (REF_OUT), C27.1, C29.2, C64.2, C71.1, C74.2
REF_ADC3: ADC1.8 (REF1+), ADC1.41 (REF2+), ADC1.49 (REF_OUT), C38.1, C51.2, C83.2, C85.2, C87.1
RESET: BC832.10 (P21/RESET), J1.10, RESET.1
RESET_ADC: ADC1.36 (!RESET), ADC2.36 (!RESET), ADC3.36 (!RESET), BC832.D1 (P23)
SDCLK: BC832.4 (SWCLK), J1.4
SDIO: BC832.3 (SWDIO), J1.2
SDI_ADC1: ADC3.20 (DCLK1/SDI), BC832.C4 (P15)
SDI_ADC2: ADC2.20 (DCLK1/SDI), BC832.B5 (P07)
SDI_ADC3: ADC1.20 (DCLK1/SDI), BC832.A1 (P28)
SDO_ADC1: ADC3.21 (DCLK0/SDO), BC832.D3 (P16)
SDO_ADC2: ADC2.21 (DCLK0/SDO), BC832.B4 (P05)
SDO_ADC3: ADC1.21 (DCLK0/SDO), BC832.B2 (P29)
SHIELD: J3.S4 (SHIELD), J3.S5 (SHIELD), J3.SH1 (SHIELD), J3.SH2 (SHIELD), J3.SH3 (SHIELD), J3.SH4 (SHIELD)
SLCK_ADC1: ADC3.19 (DCLK2/SCLK), BC832.A3 (P04)
SLCK_ADC2: ADC2.19 (DCLK2/SCLK), BC832.D2 (P19)
SLCK_ADC3: ADC1.19 (DCLK2/SCLK), BC832.C2 (P22)
START_ADC: ADC3.33 (!START), BC832.D5 (P10)
SYNC_ADC: ADC1.35 (!SYNC_IN), ADC2.35 (!SYNC_IN), ADC3.34 (!SYNC_OUT), ADC3.35 (!SYNC_IN)
USB_5VOLT+: CHARGING.13 (IN), J3.1 (VBUS), R57.2, R62.2
VCC3.3_AN: ADC1.6 (AVDD1A), ADC1.43 (AVDD1B), ADC1.52 (AVDD2B), ADC1.58 (AVDD2A), ADC1.62 (AVDD4), ADC2.6 (AVDD1A), ADC2.43 (AVDD1B), ADC2.52 (AVDD2B), ADC2.58 (AVDD2A), ADC2.62 (AVDD4), ADC3.6 (AVDD1A), ADC3.43 (AVDD1B), ADC3.52 (AVDD2B), ADC3.58 (AVDD2A), ADC3.62 (AVDD4), C2.2, C11.1, C16.2, C17.2, C23.2, C24.2, C25.2, C28.1, C30.2, C31.2, C37.1, C39.2, C40.2, C66.1, C67.2, C68.2, C69.2, C72.2, C73.2, C75.2, C77.2, C78.1, C79.2, C82.2, C84.2, C86.1, D1.1 (IN), ESD7.3 (IO2), R47.1, VCC3.3_AN.5 (OUT)
VCC3.3_DIG: ADC1.24 (IOVDD), ADC1.33 (!START), ADC1.54 (FORMAT1), ADC1.55 (FORMAT0), ADC2.24 (IOVDD), ADC2.33 (!START), ADC2.54 (FORMAT1), ADC2.55 (FORMAT0), ADC3.24 (IOVDD), ADC3.54 (FORMAT1), ADC3.55 (FORMAT0), BC832.16 (VDD), C3.2, C4.1, C6.1, C9.1, C10.2, C20.2, CLOCK.4 (VDD), ESD7.4 (IO3), J1.1, R68.2, R69.2, VCC3.3_DIG.5 (OUT)
VCC_BATTERY: C55.2, CHARGING.2 (BAT_2), CHARGING.3 (BAT), R55.2, U2.1 (+)
VIRTUAL_GND_PASSIVE: C33.2, R47.2, R58.1, SUBJECT_GND_VD.MP
V_OUT_CHARGER: C19.2, C56.2, CHARGING.6 (EN1), CHARGING.10 (OUT_2), CHARGING.11 (OUT), R41.2, R43.2, S1.1, VCC3.3_AN.1 (IN), VCC3.3_DIG.1 (IN)
XTAL_OUT: ADC1.32 (XTAL2/MCLK), ADC2.32 (XTAL2/MCLK), ADC3.32 (XTAL2/MCLK), CLOCK.3 (OUT)

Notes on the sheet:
Power Supply and Charging Circuit (configured to charge at 100mA max without tracking thermals of the battery)
POWER SUPPLY
Bluetooth

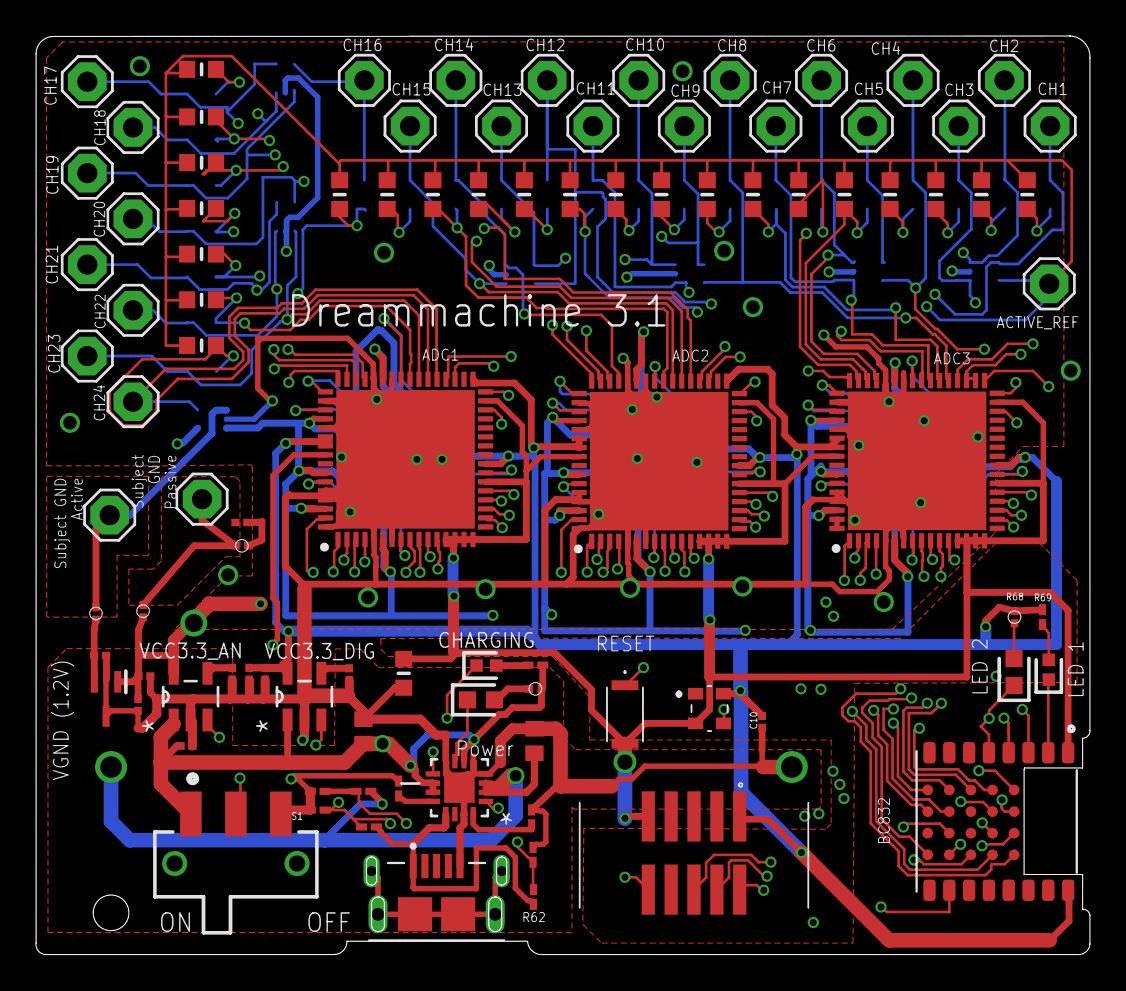
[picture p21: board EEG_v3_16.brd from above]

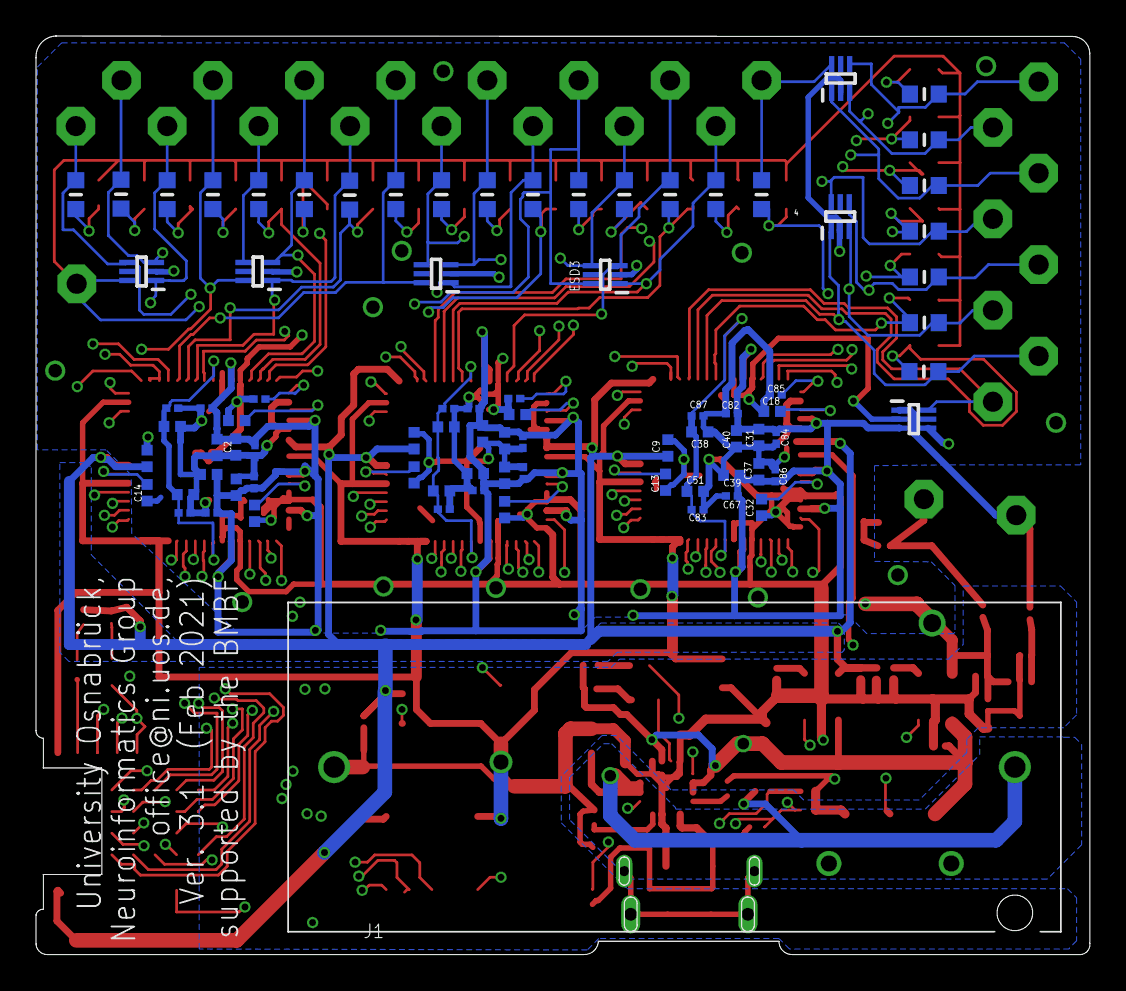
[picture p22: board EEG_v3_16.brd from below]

Board: 4 copper layers, 58.6 x 51.0 mm, 177 parts (82 on the bottom side), 110 nets.

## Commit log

2022-06-03 Create PCB Board Design
2022-06-03 PCB Board Design
    [EEG_v3_16.brd, EEG_v3_16.sch]
